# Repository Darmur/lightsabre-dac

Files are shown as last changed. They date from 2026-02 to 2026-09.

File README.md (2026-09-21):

# LightSABRE DAC

**An audiophile Raspberry Pi HAT, given away complete.**

Designed by [Dario “Darmur” Murgia](https://github.com/Darmur). Released under [CC0 1.0](LICENSE).






<p align="center">
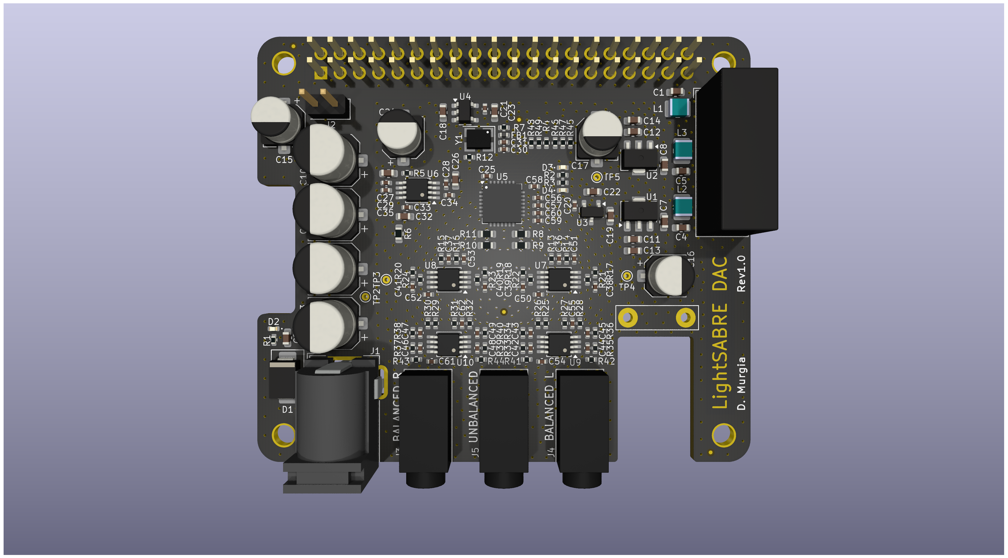
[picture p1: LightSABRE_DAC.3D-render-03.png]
LightSABRE DAC, top view — Rev 1.0 by D. Murgia
  
</p>

LightSABRE is a finished, manufacturable, dual-edition DAC for Raspberry Pi. The Gerbers, pick-and-place, 3D model, and two BOMs — already filled with LCSC, Mouser, and Digi-Key numbers — live in this repository. The work of designing it is done. What remains is to make a board, listen, and share what you heard.

---

## Why this board exists

Open audio hardware is only useful if someone can hold it. LightSABRE is a Raspberry Pi HAT built around a proper Sabre converter, with the analogue, the clocks, and the power that the datasheet assumes and most boards omit.

The name is not decoration. At the centre sits the ESS ES9018K2M, the 32-bit SABRE32 converter that made “Sabre sound” a living-room phrase: HyperStream architecture, on-chip ASRC, and a Time Domain Jitter Eliminator that forgives a Raspberry Pi’s imperfect I²S in a way cheap DAC HATs never do.

The silk reads `D. Murgia  Rev1.0`. The licence is CC0.

> Creative Commons CC0 is not a licence with strings. It is a dedication to the commons. You may manufacture LightSABRE, sell LightSABRE, modify LightSABRE, and say so. The only honest thing to keep is the name on the board.

---

## What you are looking at

<p align="center">
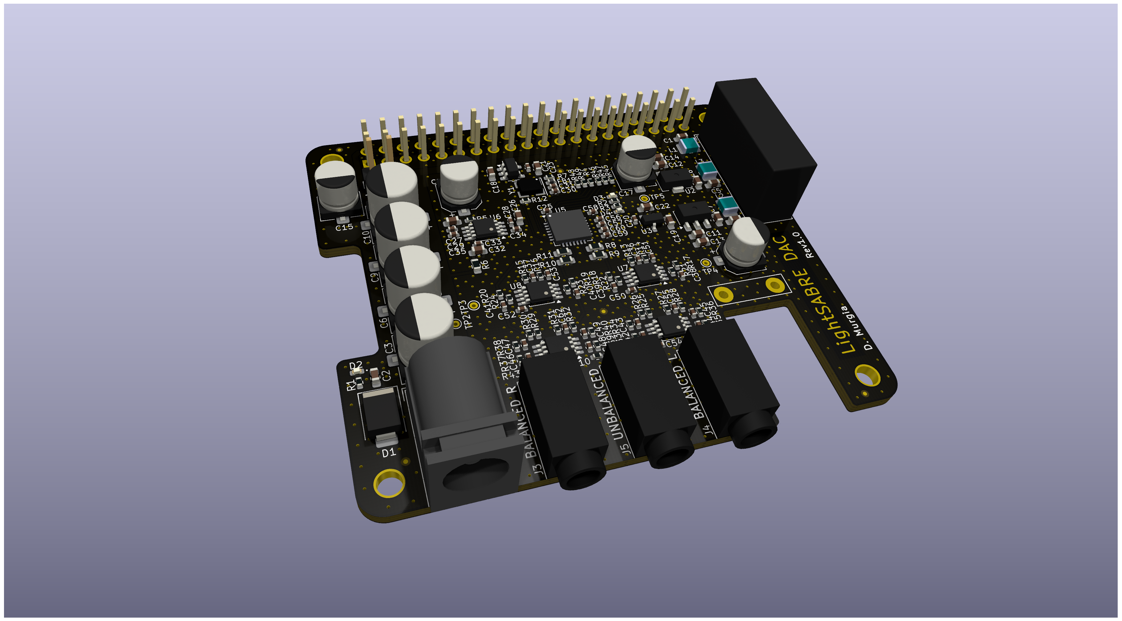
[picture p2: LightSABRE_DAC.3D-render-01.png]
LightSABRE DAC, three-quarter view with barrel jack and three 3.5 mm outputs
  
</p>

LightSABRE is a 65 × 56 mm Raspberry Pi HAT. It sits on the 40-pin GPIO, takes I²S from the Pi, and puts analogue music out of three 3.5 mm jacks:

| Jack (silkscreen) | Part | Wiring on the silk |
| --- | --- | --- |
| **Balanced L** | 3.5 mm PJ-320A | Tip = hot (+), ring = cold (−), sleeve = shield |
| **Balanced R** | 3.5 mm PJ-320A | Tip = hot (+), ring = cold (−), sleeve = shield |
| **Unbalanced** | 3.5 mm PJ-320A | Tip = left, ring = right, sleeve = shield |

The same wiring is engraved on the underside, so a late-night cable session does not require the PDF.

<p align="center">
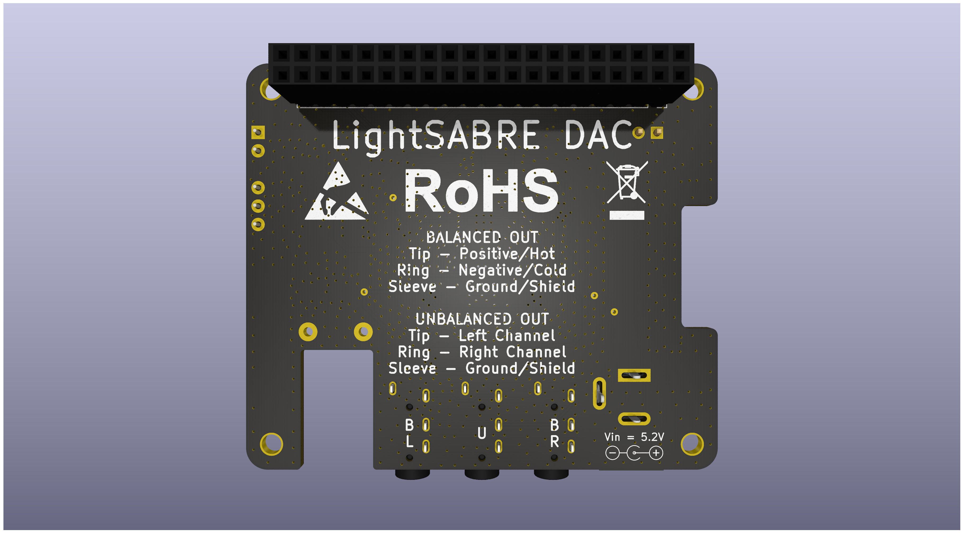
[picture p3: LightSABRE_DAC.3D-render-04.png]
LightSABRE DAC underside — output pinout and 5.2 V input polarity
  
</p>

A 5.5 × 2.0 mm barrel jack feeds the board. The silk says what the analogue section wants to see: **Vin = 5.2 V**, centre positive. A 5.6 V / 5 W SMB zener sits on that input as a clamp, not as a design suggestion to over-volt it.

A two-pin jumper (`J2` / `JP1`) ties the HAT 5 V rail to the Raspberry Pi. Fit it and the HAT can back-power the Pi, or the Pi can feed the HAT. Leave it off if you want the two 5 V domains independent.

---

## The engineering, in the order it matters

Audiophile boards fail in the power supply more often than they fail in the DAC. LightSABRE is laid out around that fact.

### Isolated analogue rails

The 5 V incoming rail does not become the op-amp supply. An isolated 2 W DC/DC module (`A0512S-2WR2`, PS1) creates a galvanically split ±12 V island. Linear 78L09 / 79L09 regulators then drop that island to quiet ±9 V for the analogue stages. The Raspberry Pi’s digital noise stays on its own side of the isolation barrier.

### Split 3.3 V for the Sabre chip

The ES9018K2M is not given a single 3.3 V and a hope.

| Rail | Regulator | Role |
| --- | --- | --- |
| DAC digital 3.3 V | LR6206B-U33 | Digital core and I/O |
| DAC analogue 3.3 V | Texas Instruments **TPS7A20** (TPS7A2033) | Low-noise analogue / clock domain |

That split — a workhorse regulator for digital, a Texas Instruments ultra-low-noise LDO for analogue — is the difference between a Sabre chip that can still measure like the datasheet and a Sabre chip that measures like a phone dongle.

### The conversion, treated as analogue

The DAC current comes out of the ES9018K2M and meets a discrete I/V and line stage built from five dual audio op-amps (`U6`–`U10`). The gain-setting resistors are 806 Ω, 0.1 %, thin-film 0402 parts — twenty of them — because current-to-voltage is where a Sabre board either becomes transparent or becomes a tone control. The filter capacitors in that path are C0G/NP0 (2.2 nF 2 % and 470 pF), not the X5R that is cheaper to pick.

Five dual packages is not excess. They implement the current-to-voltage conversion and the balanced plus unbalanced line stages, so the single-ended jack is a real analogue output rather than one half of a differential pair left hanging.

### A clock that is not an afterthought

Y1 is a 100 MHz, 3.3 V, 3225 CMOS oscillator, the frequency the ES9018K2M actually wants. The Standard and Pro editions differ here on purpose — see below — but both editions give the converter its own oscillator rather than begging a clock from the Pi.

### A HAT that behaves like a HAT

The board is a mechanical HAT: 65.1 × 56.1 mm, 1.6 mm FR4, 40-pin extended socket, mounting holes, and a cut-out that clears the Pi’s connectors. I²S, I²C, and the usual GPIO pass through. The converter’s I²C address is `0x90` in 8-bit notation, which is **`0x48`** in the 7-bit notation every Linux driver uses.

<p align="center">
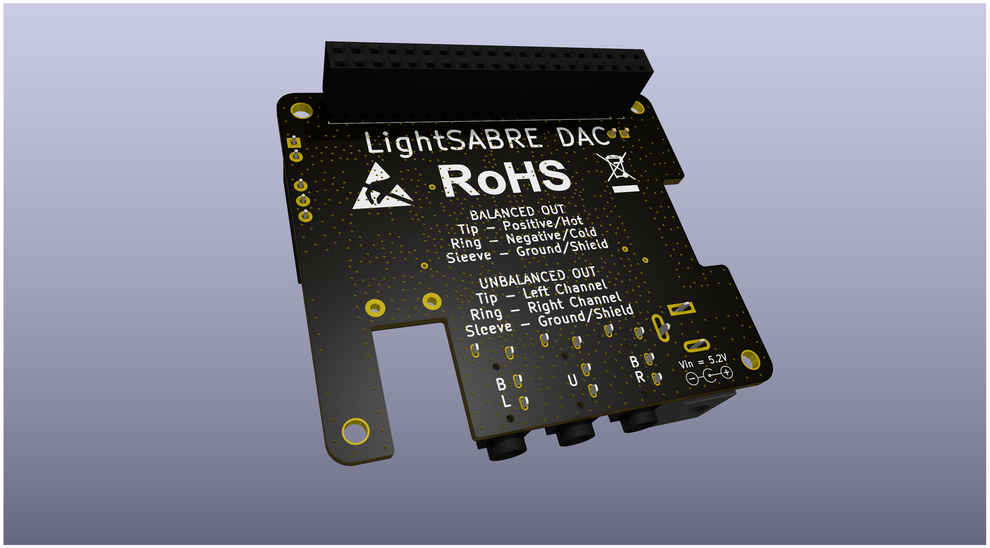
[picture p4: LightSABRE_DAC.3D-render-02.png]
LightSABRE DAC, underside three-quarter view
  
</p>

---

## Standard and Pro

One PCB. Two bills of materials. The difference is not a marketing sticker — it is two parts, chosen because they sit in the two places a listener can still hear after the power architecture is already right.

| | **Standard** — `LightSABRE_DAC.bom.varA.xlsx` | **Pro** — `LightSABRE_DAC.bom.varB.xlsx` |
| --- | --- | --- |
| **Op-amps U6–U10** | Texas Instruments **OPA1678** | Texas Instruments **OPA1602** |
| **Op-amp character** | SoundPlus FET-input, 4.5 nV/√Hz, the honest high-performance default | SoundPlus bipolar-input, 1.1 nV/√Hz, the quieter, more expensive sibling |
| **Oscillator Y1** | CMOS crystal oscillator, 100 MHz / 20 ppm (`O93225100MEDA4SI-13`) | SiTime **SiT8209** MEMS oscillator, 100 MHz / 20 ppm |
| **Clock character** | Correct frequency, serviceable jitter, easy to source | MEMS stability, vibration immunity, the part you specify when the rest of the board deserves it |
| **Everything else** | Identical | Identical |

The isolated DC/DC, the TPS7A20, the 0.1 % I/V resistors, the C0G filter caps, the Sabre chip, the jacks, and the HAT mechanics do not change. This is not a “lite” board and a “real” board. It is one analogue design and two component grades, so a first build can be affordable and a second build can be uncompromising without a respin.

If you are assembling a single board and the Pro parts are in stock, fit the Pro parts. If you are assembling a small run and want every unit to exist, Standard is not a consolation prize.

---

## What the converter will do

From the ES9018K2M, once the board around it is this careful:

- PCM up to **32-bit / 384 kHz**
- DSD up to **DSD256**
- On-chip ASRC and jitter elimination
- Datasheet territory of **127 dB DNR** and **−120 dB THD+N**
- I²C register map for volume, filters, and de-emphasis

Those figures are the chip’s. The board is designed so they remain plausible after the signal has left the QFN.

---

## Repository contents

Everything required to order, assemble, inspect, and understand Rev 1.0.

| File | What it is |
| --- | --- |
| `LightSABRE_DAC.kicad_pro` / `.kicad_sch` / `.kicad_pcb` | KiCad 9 project. Sheets: **power**, **audio**, **interface**. |
| `power.kicad_sch` | Input protection, isolated ±12 V, ±9 V analogue, split 3.3 V. |
| `audio.kicad_sch` | ES9018K2M, clock, I/V, balanced and unbalanced outputs. |
| `interface.kicad_sch` | Raspberry Pi 40-pin HAT pinout, I²S and I²C. |
| `LightSABRE_DAC.sch.pdf` | Printable schematic. |
| `LightSABRE_DAC.pcb.pdf` | Printable board. |
| `LightSABRE_DAC.bom.varA.xlsx` | **Standard** BOM with MPN, LCSC, Mouser, Digi-Key. |
| `LightSABRE_DAC.bom.varB.xlsx` | **Pro** BOM. Same columns. Different U6–U10 and Y1. |
| `LightSABRE_DAC.pos.csv` | Centroid / pick-and-place. |
| `LightSABRE_DAC.gerber_x1.2-Layers.zip` | 2-layer Gerbers, classic Protel extensions. |
| `LightSABRE_DAC.gerber_x1.4-Layers.zip` | 4-layer Gerbers, classic Protel extensions. |
| `LightSABRE_DAC.gerber_x2.2-Layers.zip` | 2-layer Gerbers, KiCad X2 / `.gbr` naming, split PTH/NPTH drills. |
| `LightSABRE_DAC.gerber_x2.4-Layers.zip` | 4-layer Gerbers, KiCad X2 naming. |
| `LightSABRE_DAC.3D-model.step` | Full 3D for enclosure work. |
| `LightSABRE_DAC.3D-render-0[1-4].png` | The renders on this page. |
| `LICENSE` | CC0 1.0 Universal. |

---

## Make one

The manufacturing pack is not a teaser. It is the order.

### 1. Choose a stack-up

Both 2-layer and 4-layer plots are in the tree. The design rules are 0.1524 mm (6 mil) clearance and trace, 35 µm copper, 1.6 mm finished thickness.

**Order the 4-layer board** unless a fab house forces the issue. Inner planes are how a Sabre HAT keeps digital return current out of the analogue. The 2-layer set exists so the project remains buildable when a four-layer panel is not.

Suggested 4-layer reading of the exported job file:

| Layer | Role |
| --- | --- |
| F.Cu | Signals, analogue, components |
| In1.Cu | Plane |
| In2.Cu | Plane |
| B.Cu | Signals and HAT socket |

Finish is left open in the job file. ENIG is the grown-up choice for a 0.5 mm-pitch QFN and 0402 I/V network; HASL will work if the assembler is honest about it.

### 2. Choose a Gerber dialect

| Archive prefix | Give this to |
| --- | --- |
| `gerber_x1.*` | Fabs that still want `.gtl` / `.gbl` / `.gto` and a single `.drl` |
| `gerber_x2.*` | Fabs that want modern `.gbr` names and separate PTH / NPTH drills |

If you are unsure, send `LightSABRE_DAC.gerber_x2.4-Layers.zip` and the matching BOM. Most houses in 2026 prefer it.

### 3. Choose Standard or Pro

Upload `LightSABRE_DAC.bom.varA.xlsx` or `LightSABRE_DAC.bom.varB.xlsx` with `LightSABRE_DAC.pos.csv`. LCSC numbers are already in the sheets. Fiducials `FID1`–`FID6` are on the board because this was always meant to go through a pick-and-place.

### 4. Respect the parts that look small

This is not a first hot-air project.

- ES9018K2M is a **5 × 5 mm QFN-28**, 0.5 mm pitch, thermal pad with vias
- Most of the analogue network is **0402**
- The I/V resistors are 0.1 % thin film — do not “equivalent” them to 1 % thick film
- The barrel jack is **5.5 × 2.0 mm**, not the more common 2.1 mm pin
- The isolated DC/DC is a tall SIP. Check enclosure height before you print a case

Professional assembly is the path that honours the layout. A careful hand build is possible; a careless one will spend three evenings chasing a pin that the stencil would have got in eight seconds.

### 5. First power, before first music

1. Inspect the QFN and the DC/DC orientation.
2. Leave `JP1` off.
3. Feed **5.2 V** centre-positive into `J1`. Confirm the input LED.
4. Measure the isolated island: roughly ±12 V after PS1, ±9 V after U1/U2.
5. Measure both 3.3 V rails at the DAC.
6. Only then seat the HAT on a Pi, decide whether `JP1` should be on, and bring I²S up.

If a rail is wrong, stop. The gift is a working board, not a smoked Sabre.

---

## Bring it up on a Raspberry Pi

LightSABRE speaks the language every Pi DAC already speaks.

- **I²S** from the 40-pin header into the ES9018K2M
- **I²C** at **0x48** (7-bit) for volume, filters, and mute
- Overlay starting point on Raspberry Pi OS / Volumio / moOde / DietPi: a generic I²S DAC, then an ES9018K2M userspace or kernel client if you want hardware volume

Use what fits. Publish what you change.

Suggested first listen, so reports can be compared:

- Same file, same headphones or the same pair of TRS cables
- Unbalanced jack first, then balanced into something that can take it
- One track you know too well, one you have never heard on a Sabre chip
- Note the edition (Standard or Pro), the stack-up (2-layer or 4-layer), the Pi model, and the player

---

## The invitation

The expensive part is already in the tree: the thinking, the layout, the variants, the fab files, and the decision to give them away.

The interesting part left is not another respin. It is a board that exists, a listening chair, and a short write-up that the next builder can trust.

Build a Standard. Build a Pro. Build one of each and swap only the op-amps in your notes. Photograph the underside. Post the first-power rail measurements. Say whether the isolated island was worth it on *your* Pi. Open an issue, or a pull request with a build log, or a thread wherever you already talk about DACs.

If the board taught you something, write it down. That is how an open hardware gift stays alive after the ZIP files stop being news.

---

## Author

**Dario Murgia ([Darmur](https://github.com/Darmur))**  
Italian electronics engineer. Other open audio boards: [BassOwl-HAT](https://github.com/Darmur/bassowl-hat), [BassOwl-Lite](https://github.com/Darmur/bassowl-lite), [BassFly-uHAT](https://github.com/Darmur/bassfly-uhat), [BassCrab-uHAT](https://github.com/Darmur/basscrab-uhat), [tubeamp](https://github.com/Darmur/tubeamp). Schematic title block: *itz-embedded*, 2026-01-09, Rev 1.0.

---

## License

[CC0 1.0 Universal](LICENSE). To the extent possible under law, the author has waived all copyright and related rights to this work.

ESS SABRE, SABRE32, and related marks are trademarks of ESS Technology, Inc. Raspberry Pi is a trademark of Raspberry Pi Ltd. Texas Instruments and SiTime part names are used here as the actual parts on the BOMs.

---

<p align="center"><em>Make the board. Listen for a week. Tell someone what it did.</em></p>

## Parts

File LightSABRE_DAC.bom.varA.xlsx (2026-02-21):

Qty | Reference | Descr | MPN | Footprint | Datasheet | Value | MOUSER | DIGIKEY | LCSC
14 | C1, C4, C5, C7, C8, C13, C14, C18, C19, C22, C23, C26, C27, C32 | CAP CER 10UF 20% 16V X5R 0603 | HGC0603R5106M160NTHJ | Capacitor_SMD:C_0603_1608Metric | ~ | CAP-10U-20%-16V-X5R-0603_004 | - | - | C7472959
3 | C2, C11, C12 | CAP CER 100NF 10% 50V X7R 0603 | CGA0603X7R104K500JT | Capacitor_SMD:C_0603_1608Metric | ~ | CAP-100N-10%-50V-X7R-0603_002 | - | - | C6119867
4 | C3, C6, C9, C10 | CAP ALUM 470UF 20% 10V SMD | RVT1A471M0607 | Capacitor_SMD:CP_Elec_6.3x7.7 | https://www.lcsc.com/datasheet/lcsc_datasheet_2411220152_ROQANG-RVT1A471M0607_C335982.pdf | CAP-EL-470U-20%-10V-ALUM-6.3MM-7.7MM_002 | - | - | C335982
4 | C15, C16, C17, C24 | CAP ALUM 100UF 20% 16V SMD | RVT1C101M0505 | Capacitor_SMD:CP_Elec_5x5.4 | https://www.lcsc.com/datasheet/lcsc_datasheet_2411121455_ROQANG-RVT1C101M0505_C2977550.pdf | CAP-EL-100U-20%-16V-ALUM-5.0MM-5.4MM_002 | - | - | C2977550
6 | C20, C21, C28, C29, C31, C33 | CAP CER 100NF 10% 16V X7R 0402 | FCC0402B104K160AT | Capacitor_SMD:C_0402_1005Metric | ~ | CAP-100N-10%-16V-X7R-0402_002 | - | - | C5137468
12 | C25, C30, C34, C35, C50, C51, C52, C53, C54, C55, C61, C62 | CAP CER 2.2UF 20% 16V X5R 0402 | CGA0402X5R225M160GT | Capacitor_SMD:C_0402_1005Metric | ~ | CAP-2.2U-20%-16V-X5R-0402_002 | - | - | C6119773
7 | C36, C37, C56, C57, C58, C59, C60 | CAP CER 4.7UF 20% 10V X5R 0402 | HGC0402R5475M100NTEJ | Capacitor_SMD:C_0402_1005Metric | ~ | CAP-4.7U-20%-10V-X5R-0402_002 | - | - | C7472957
4 | C38, C39, C40, C41 | CAP CER 470PF 5% 50V C0G 0402 | CGA0402C0G471J500GT | Capacitor_SMD:C_0402_1005Metric | ~ | CAP-470P-5%-50V-C0G-0402_002 | - | - | C20069335
8 | C42, C43, C44, C45, C46, C47, C48, C49 | CAP CER 2.2NF 2% 50V C0G 0402 | GRM1555C1H222GA01D | Capacitor_SMD:C_0402_1005Metric | ~ | CAP-2.2N-2%-50V-C0G-0402_001 | 81-GRM1555C1H222GA1D | 490-GRM1555C1H222GA01DCT-ND | C2987940
1 | D1 | DIODE ZENER 5.6V 5W SMB | SMBJ5339B | Diode_SMD:D_SMB | https://datasheet.lcsc.com/lcsc/2207271730_LGE-SMBJ5339B_C5122124.pdf | ZENER-5.6V-5W-SMB_003 | - | - | C5122124
3 | D2, D3, D4 | LED RED CLEAR 0402 | XL-1005SURC | LED_SMD:LED_0402_1005Metric | https://www.lcsc.com/datasheet/C25503345.pdf | LED-RED-0402_002 | - | - | C25503345
1 | FB1 | FERRITE BEAD 600OHM@100MHZ 0.7A 0.34OHM 0402 | PBY100505T-601Y-N | Inductor_SMD:L_0402_1005Metric | https://datasheet.lcsc.com/lcsc/1811141621_Chilisin-Elec-PBY100505T-601Y-N_C142082.pdf | FERR-BEAD-600OHM@100MHZ-0.7A-0.34OHM-0402 | - | - | C142082
1 | J1 | DC BARREL JACK 5.5X2.0MM TH | DC-005 5.5-2.0MM | dm_CONN:BarrelJack | https://datasheet.lcsc.com/lcsc/1811051112_BOOMELE-Boom-Precision-Elec-DC-005-2-0_C16214.pdf | BARREL-JACK-SW_002 | - | - | C16214
1 | J2 | CONN HEADER TH 2POS 01X02 2.54MM | C124375 | Connector_PinHeader_2.54mm:PinHeader_2x01_P2.54mm_Vertical | https://datasheet.lcsc.com/szlcsc/1811151421_Ckmtw-Shenzhen-Cankemeng-C124375_C124375.pdf | CONN-HDR-01X02-2.54-TH_002 | - | - | C124375
3 | J3, J4, J5 | AUDIO JACK 3.5" 4 POLES TRRS TH | PJ-320A | dm_CONN:TRRS-PJ-320A | https://datasheet.lcsc.com/szlcsc/1912111437_SHOU-HAN-PJ-320D_C431535.pdf | PJ-320A | - | - | C2884926
1 | J6 | CONN SOCKET TH 40POS 02X20 2.54MM EXT PIN | 2.54-2*20PPC104 | dm_CONN:SKT-02x20-TH-EXT | https://www.lcsc.com/datasheet/lcsc_datasheet_1811132110_BOOMELE-Boom-Precision-Elec-2-54-2-20PPC104_C35165.pdf | RPi-GPIO-SKT-TH-EXT_002 | - | - | C35165
1 | JP1 | CONN SHUNT 2POS 2.54MM BLACK CAPPED | HY-2540-B1NIB |  | https://www.lcsc.com/datasheet/lcsc_datasheet_2410122012_HanElectricity-HY-2540-B1NIB_C18185738.pdf | CONN-SHUNT-2P-2.54MM-BLACK-CAPPED_002 | - | - | C18185738
3 | L1, L2, L3 | IND 4.7 UH 20% 1.55A 0.196 OHM 1008 | WIP252012P-4R7ML | dm_SMD:L_1008_2520Metric | https://www.lcsc.com/datasheet/lcsc_datasheet_2410121513_INPAQ-WIP252012P-4R7ML_C964123.pdf | IND-4.7U-20%-1.55A-0.196OHM-1008_002 | - | - | C964123
1 | PS1 | ISOLATED DC DC CONVERTER 5V DUAL OUT+/-12V 2W SIP | A0512S-2WR2 | Converter_DCDC:Converter_DCDC_XP_POWER-IHxxxxS_THT | https://www.lcsc.com/datasheet/lcsc_datasheet_2401211050_YLPTEC-A0512S-2WR2_C5369424.pdf | A0512S-2W-1.5KV-SIP_002 | - | - | C5369424
3 | R1, R2, R3 | RES 1K OHM 5% 1/16W 0402 | 0402WGJ0102TCE | Resistor_SMD:R_0402_1005Metric | ~ | RES-1K-5%-0.063W-0402_002 | - | - | C25543
5 | R4, R5, R7, R13, R15 | RES 10K OHM 1% 1/16W 0402 | RTT021002FTH | Resistor_SMD:R_0402_1005Metric | ~ | RES-10K-1%-0.063W-0402_002 | - | - | C102749
1 | R6 | RES 3.3 OHM 1% 1/10W 0603 | FRC0603F3R30TS | Resistor_SMD:R_0603_1608Metric | ~ | RES-3.3-1%-0.1W-0603_002 | - | - | C2930016
4 | R8, R9, R10, R11 | RES 0 OHM 1% 1/16W 0603 | FRC0603F0000TS | Resistor_SMD:R_0603_1608Metric | ~ | RES-0-1%-0.1W-0603_002 | - | - | C2906974
14 | R12, R17, R18, R19, R20, R41, R42, R43, R44, R45, R46, R47, R48, R49 | RES 10 OHM 1% 1/16W 0402 | FRC0402F10R0TS | Resistor_SMD:R_0402_1005Metric | ~ | RES-10-1%-0.063W-0402_002 | - | - | C2906862
2 | R14, R16 | RES 3.9K OHM 1% 1/16W 0402 | FRC0402F3901TS | Resistor_SMD:R_0402_1005Metric | ~ | RES-3.9K-1%-0.063W-0402_002 | - | - | C2909346
20 | R21, R22, R23, R24, R25, R26, R27, R28, R29, R30, R31, R32, R33, R34, R35, R36, R37, R38, R39, R40 | RES 806 OHM 0.1% 1/16W THIN FILM 0402 | RT0402BRD07806RL | Resistor_SMD:R_0402_1005Metric | ~ | RES-806-0.1%-0.063W-THIN-0402_001 | 603-RT0402BRD07806RL | YAG1481CT-ND | C852922
1 | U1 | IC REG LINEAR 9V 100MA SOT89-3 | 78L09 | dm_SMD:SOT-89-3 | https://www.lcsc.com/datasheet/lcsc_datasheet_2410121529_HL-78L09_C22458782.pdf | 78L09-SOT89_002 | - | - | C22458782
1 | U2 | IC REG LINEAR -9V 100MA SOT89-3 | PJ79L09SQ | dm_SMD:SOT-89-3 | https://www.lcsc.com/datasheet/lcsc_datasheet_2410221617_PJSEMI-PJ79L09SQ_C41784049.pdf | 79L09-SOT89_002 | - | - | C41784049
1 | U3 | IC REG LINEAR 3.3V 300MA SOT23-3 | LR6206B-U33 | Package_TO_SOT_SMD:SOT-23 | https://www.lcsc.com/datasheet/lcsc_datasheet_2212192008_LR-LR6206B-U33_C5336486.pdf | LR6206B-U33 | - | - | C5336486
1 | U4 | IC REG LINEAR 3.3V 300MA LOW-NOISE SOT23-5 | TPS7A2033PDBVR | Package_TO_SOT_SMD:SOT-23-5 | https://www.ti.com/lit/ds/symlink/tps7a20.pdf | TPS7A2033-SOT23 | 595-TPS7A2033PDBVR | 296-TPS7A2033PDBVRCT-ND | C2862740
1 | U5 | IC DAC 16/24/32BIT 384K DSD256 QFN28 | ES9018K2M | dm_SMD:QFN-28-1EP_5x5mm_P0.5mm_EP3.25x3.25mm_ThermalVias_0.3mm | https://www.mouser.com/datasheet/3/3763/1/ES9018K2M-Datasheet-v3.7.pdf | ES9018K2M | 460-ES9018K2M | - | C2688377
5 | U6, U7, U8, U9, U10 | IC OPAMP AUDIO 2 CIRCUIT 4.5V/36V VSSOP-8 | OPA1678IDGKR | Package_SO:MSOP-8_3x3mm_P0.65mm | https://www.ti.com/lit/ds/symlink/opa1678.pdf | OPA1678-VSSOP | 595-OPA1678IDGKR | 296-47667-1-ND | C2863133
1 | Y1 | OSC 3.3V 100MHZ 20PPM 3225 | O93225100MEDA4SI-13 | dm_SMD:Oscillator_SMD_4Pin_3.2x2.5mm | https://www.lcsc.com/datasheet/C496694.pdf | OSC-XO-100M-3225_002 | - | - | C496694

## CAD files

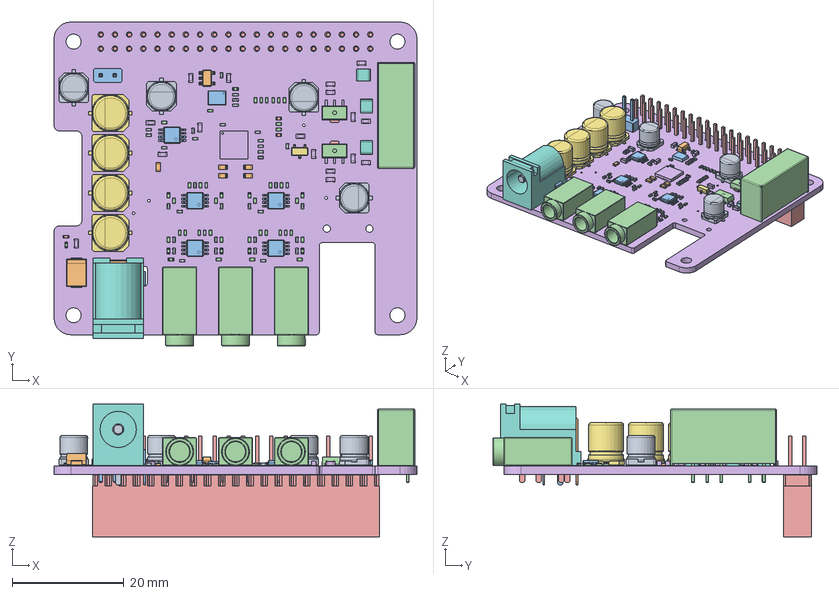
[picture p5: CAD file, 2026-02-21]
LightSABRE_DAC.3D-model.step
65.0 x 58.0 x 23.7 mm
C_0402_1005Metric x 37
D_SMB
OSC_SMD_3225
R_0402_1005Metric x 44
LED_0402_1005Metric x 3
C_0603_1608Metric x 17
CP_Elec_6.3x7.7 x 4
L_1008_2520Metric x 3
CP_Elec_5x5.4 x 4
R_0603_1608Metric x 5
MSOP-8_3x3mm_P0.65mm x 5
PJ-320A x 3
QFN28_5x5_0.5
L_0402_1005Metric
SOT-23-5
PinHeader_2x01_P2.54mm_Vertical
Volumio_Zero-HAT 1.95.1 x 2
SOT-23
BarrelJack
Converter_DCDC_XP_POWER-IHxxxxS_THT
SKT-02x20-TH-EXT
LightSABRE_DAC_PCB

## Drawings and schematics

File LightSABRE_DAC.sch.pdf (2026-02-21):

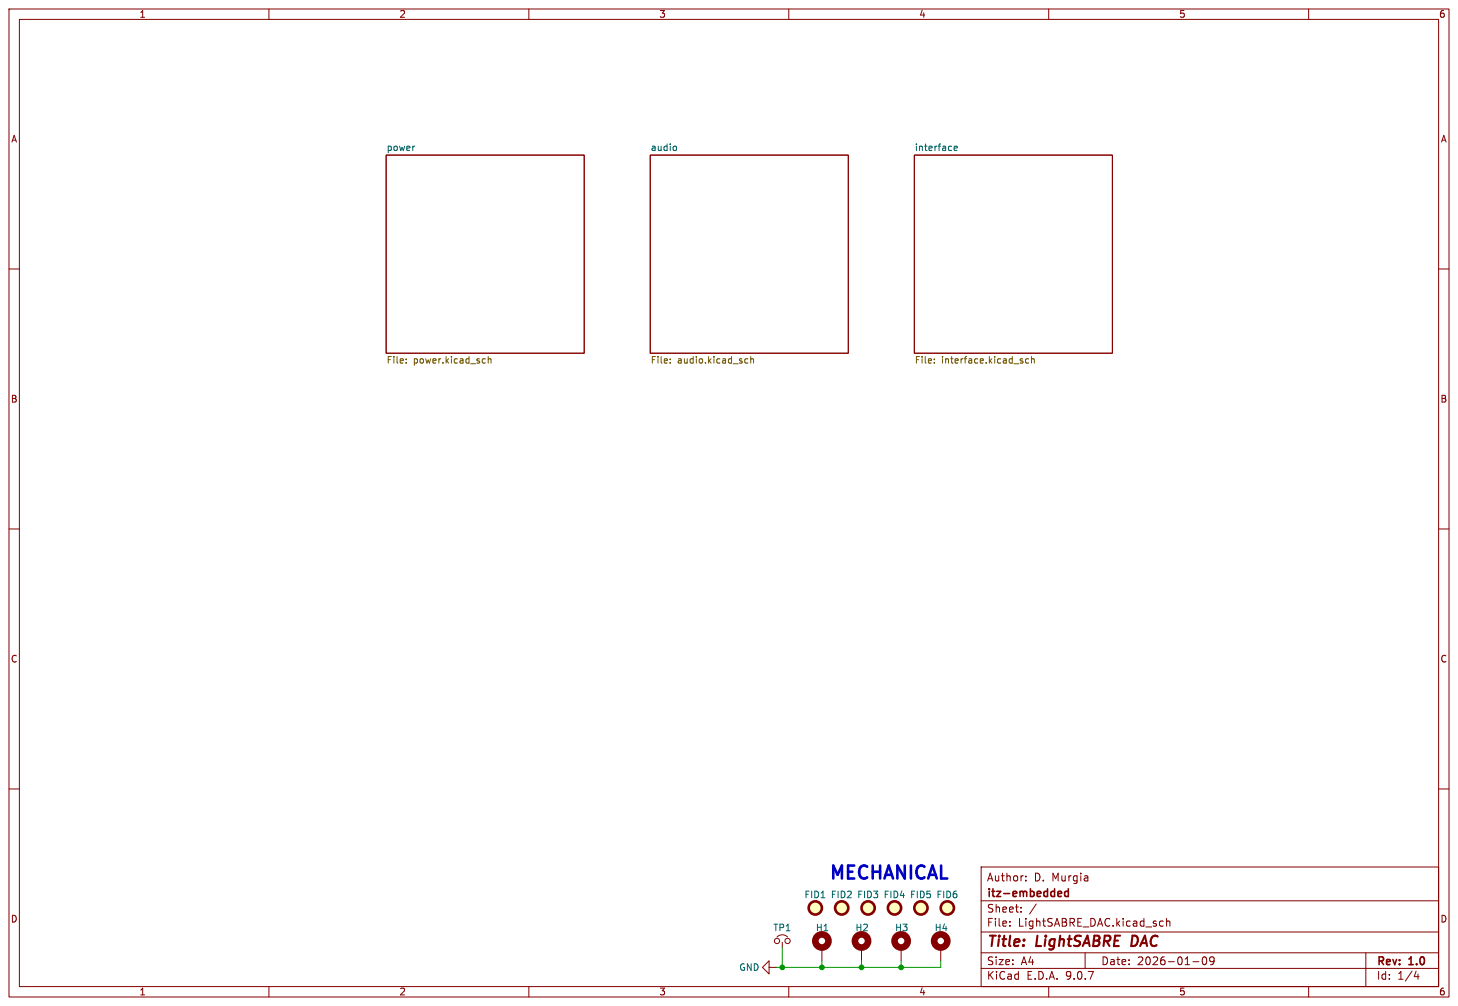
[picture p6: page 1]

Id: 1/4 Title: LightSABRE DAC

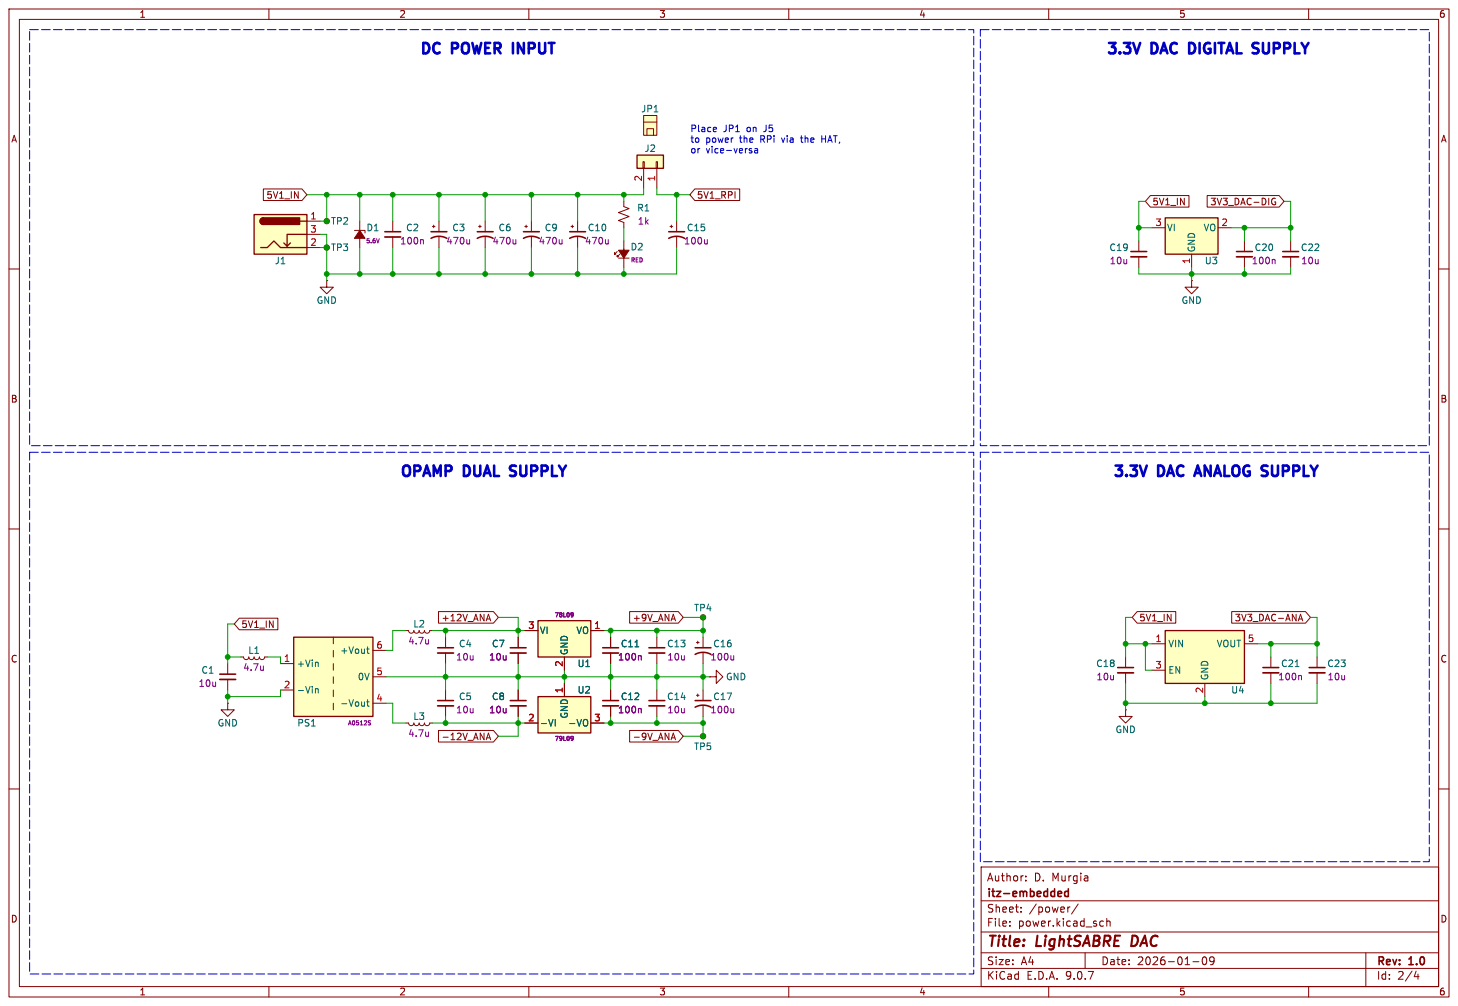
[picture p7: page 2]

Id: 2/4 Title: LightSABRE DAC

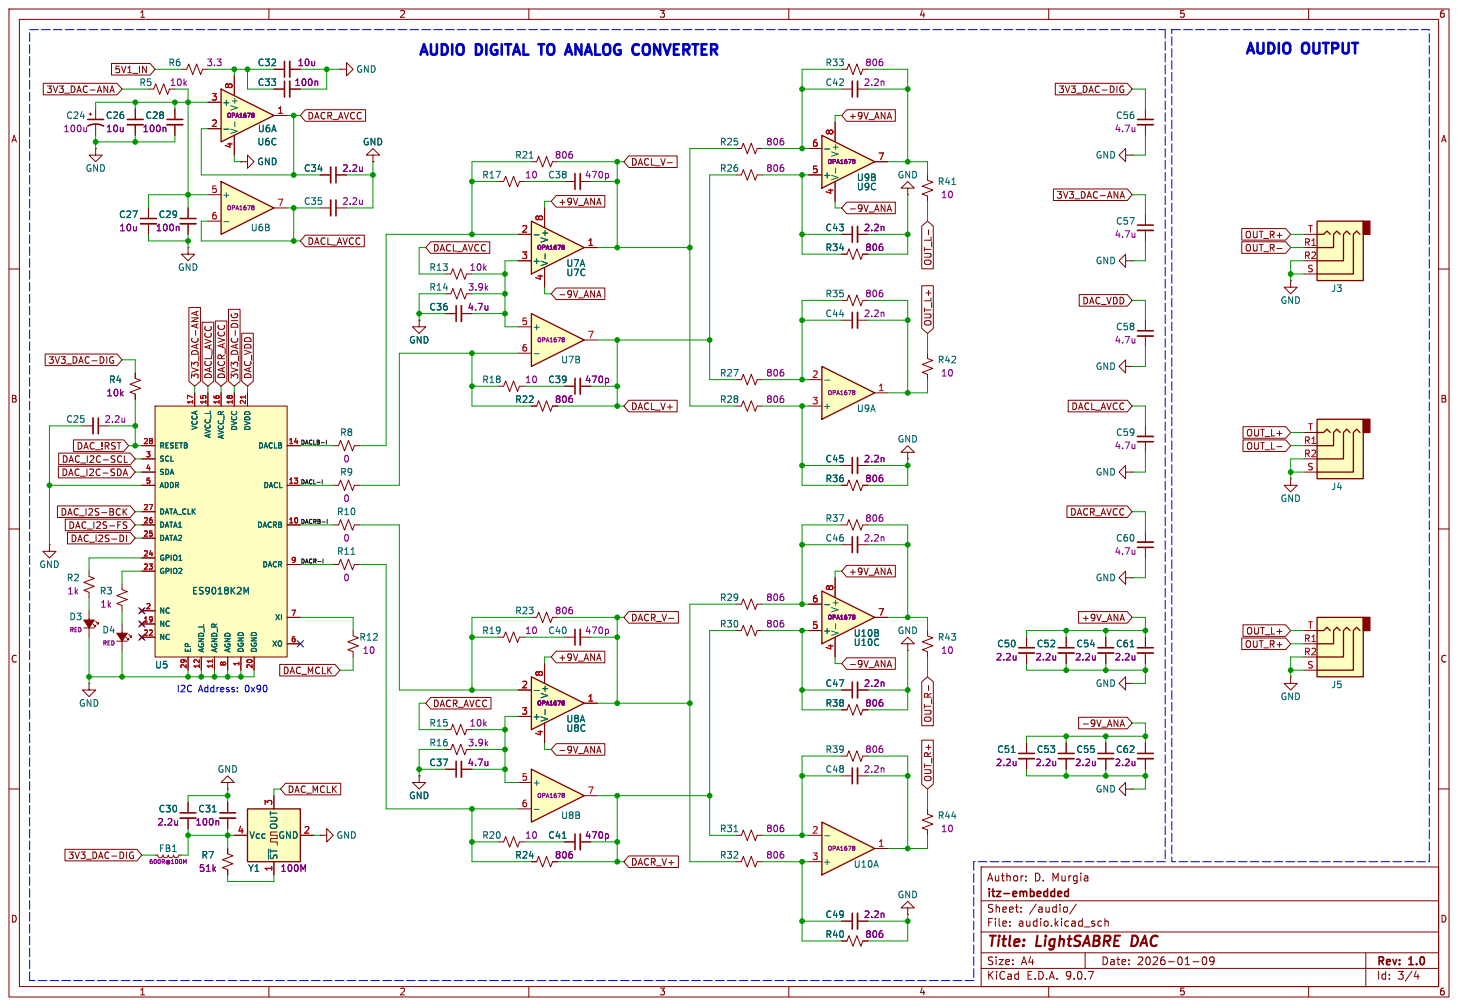
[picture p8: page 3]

1 DVDD 21 DGND 20 DACLB 14 DACL 13 DACRB 10 DACR 9 XI 7 XO 6 U5 ES9018K2M

1 DVDD 21 DGND 20 DACLB 14 DACL 13 DACRB 10 DACR 9 XI 7 XO 6 GND

File: audio.kicad_sch Sheet: /audio/
Id: 3/4 Title: LightSABRE DAC

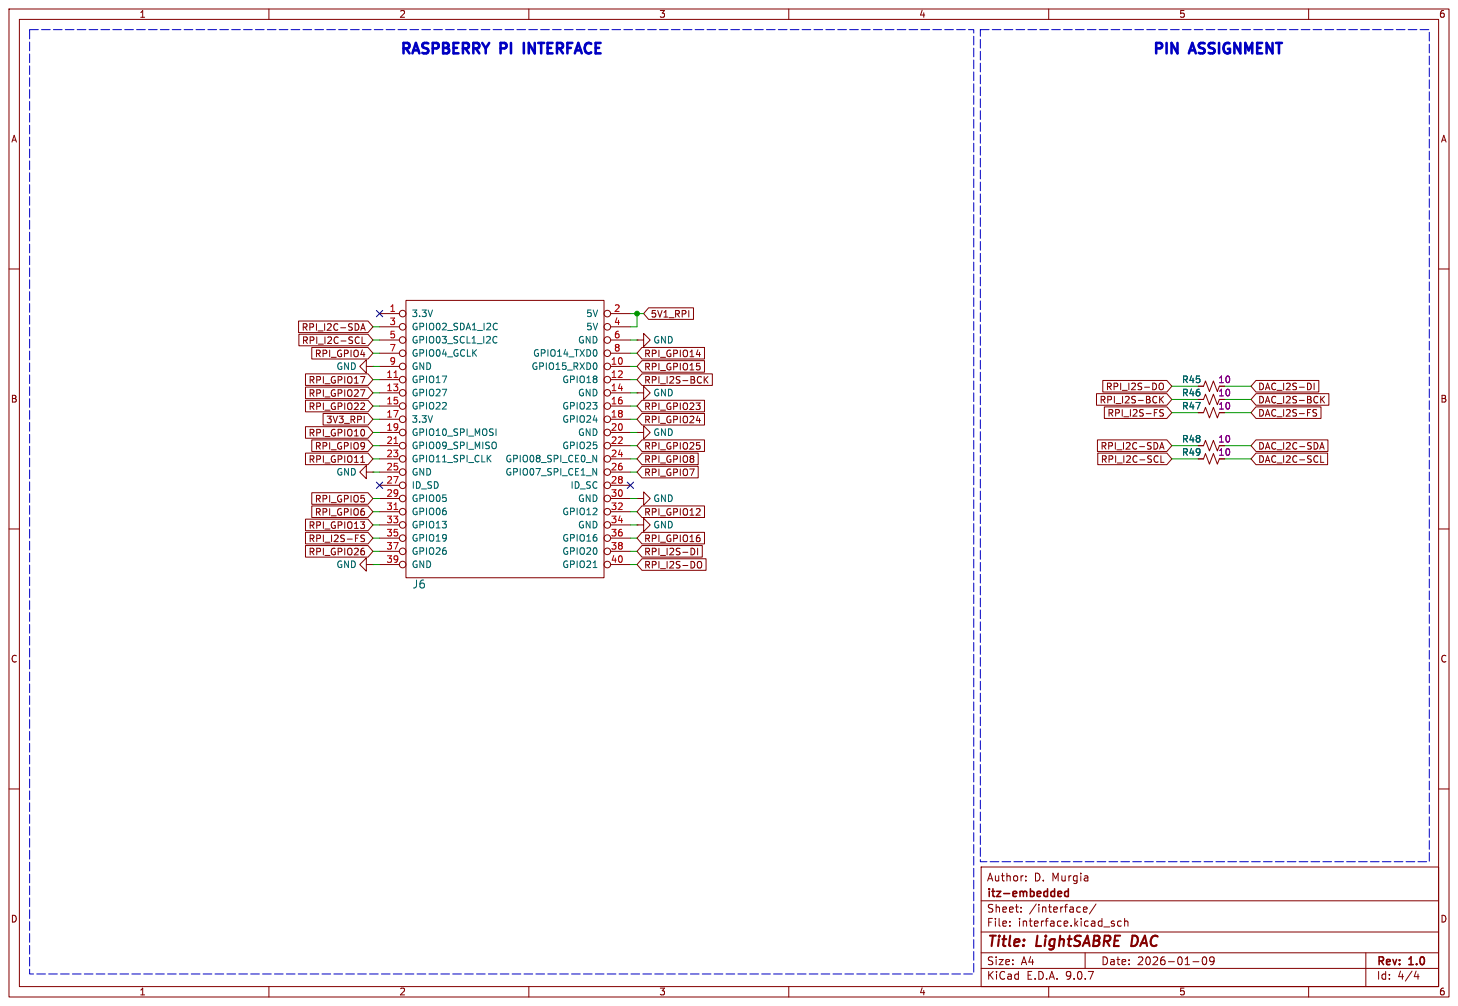
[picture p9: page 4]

File: interface.kicad_sch Sheet: /interface/
Id: 4/4 Title: LightSABRE DAC

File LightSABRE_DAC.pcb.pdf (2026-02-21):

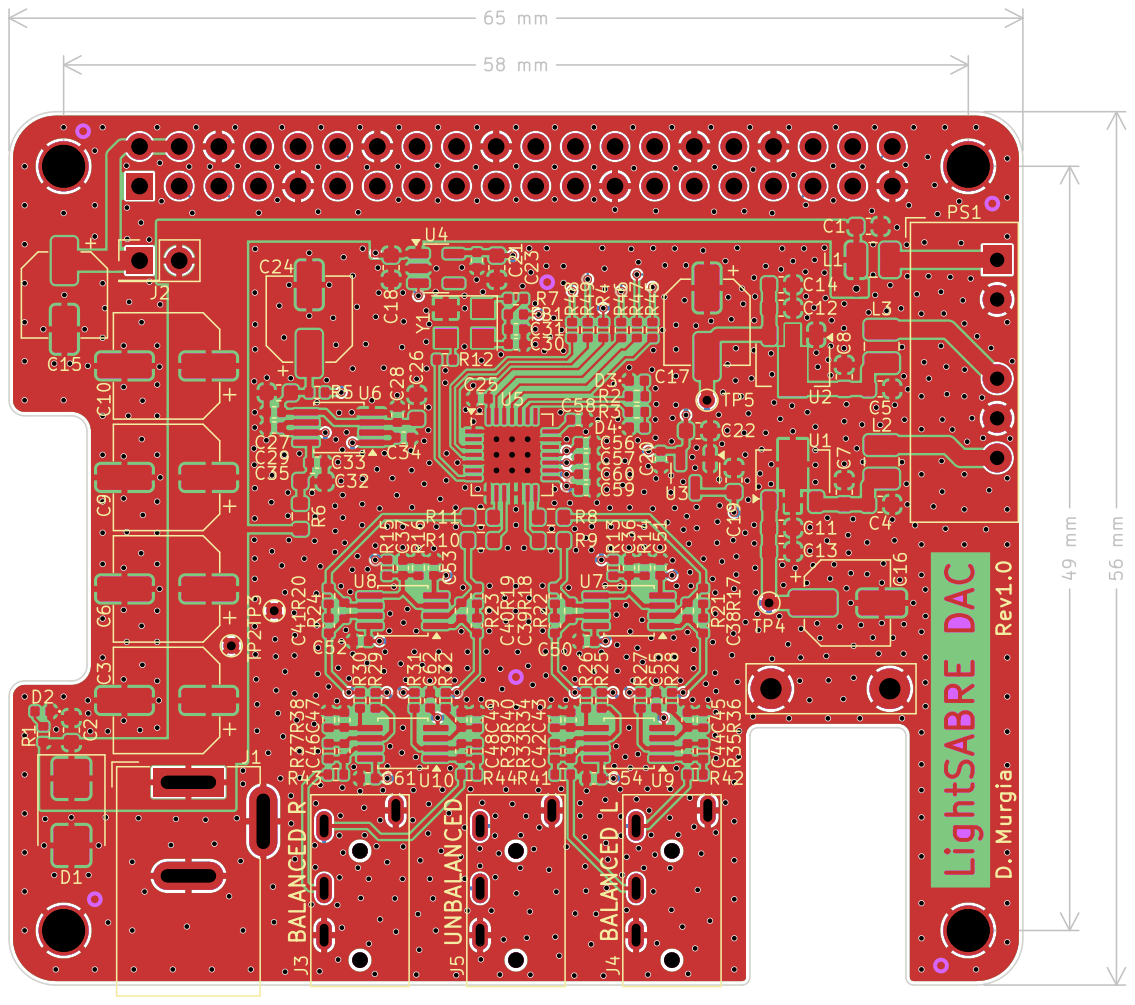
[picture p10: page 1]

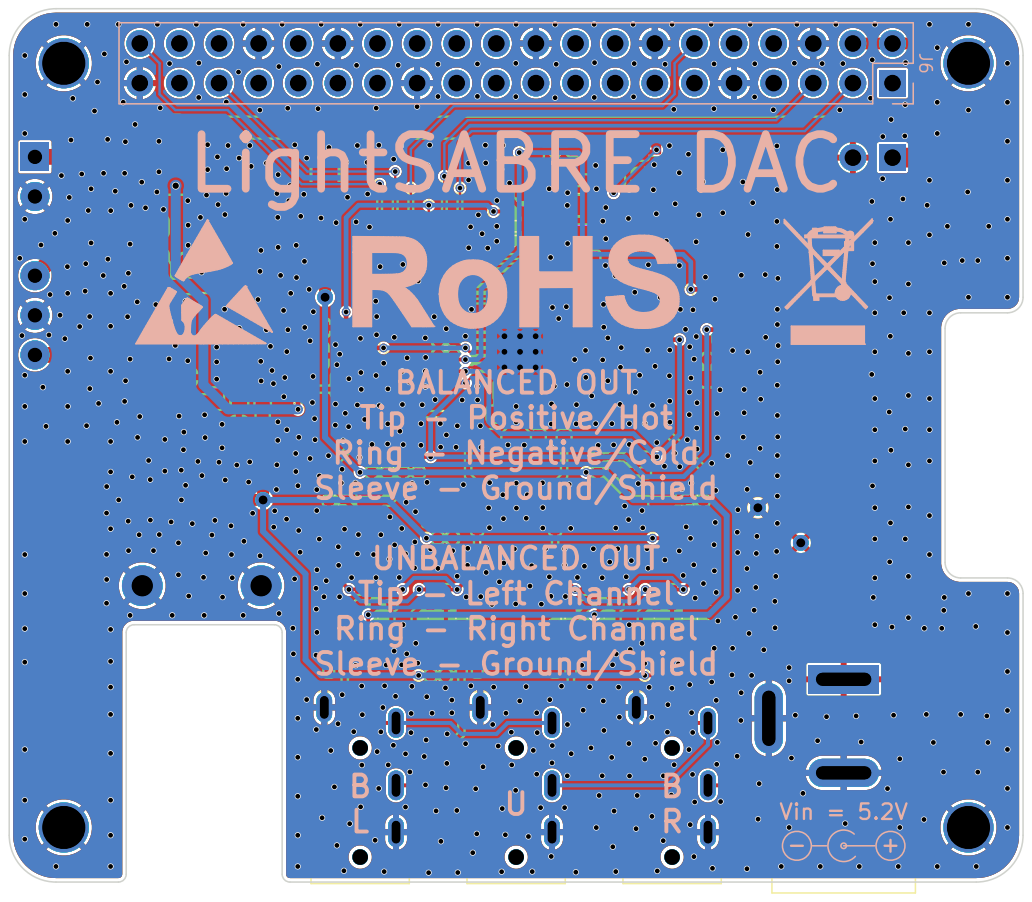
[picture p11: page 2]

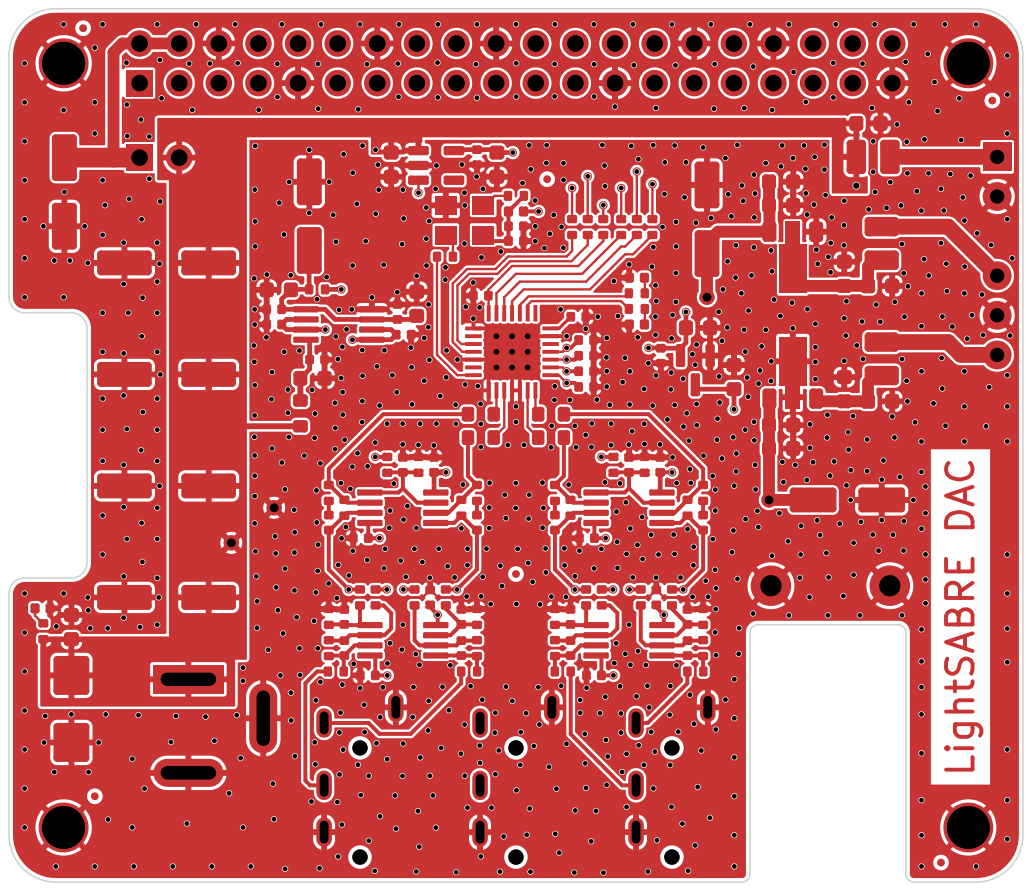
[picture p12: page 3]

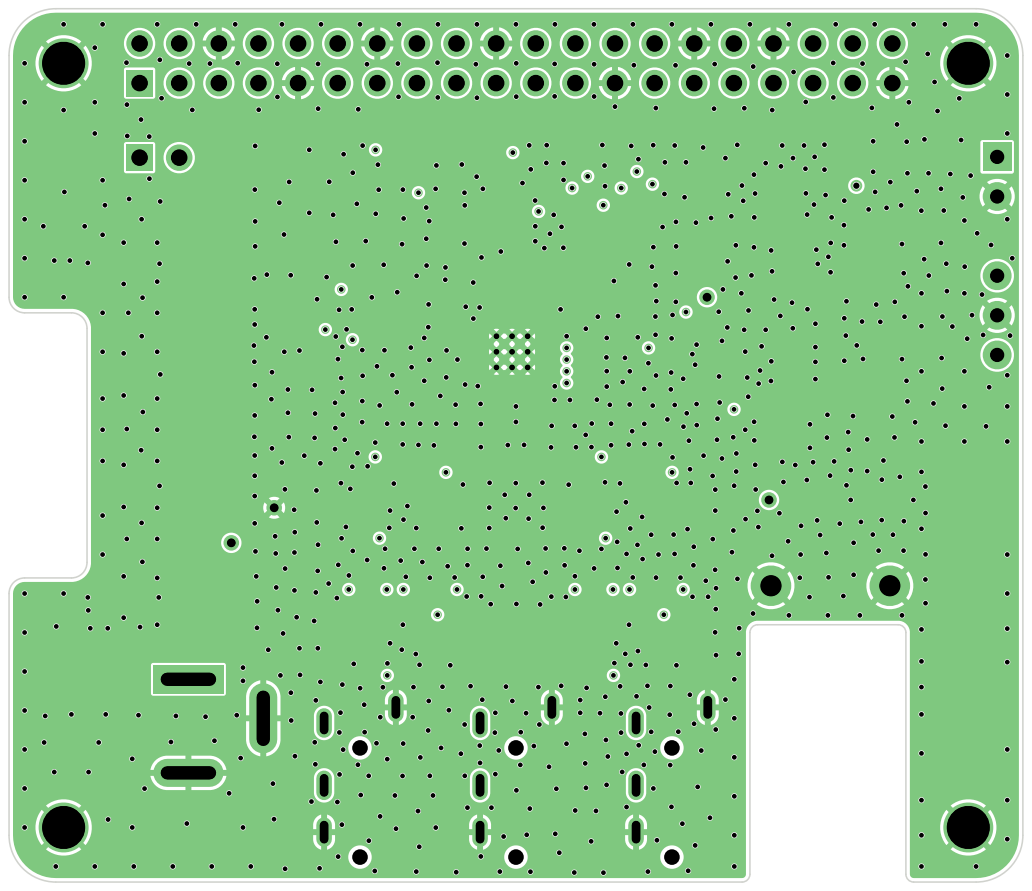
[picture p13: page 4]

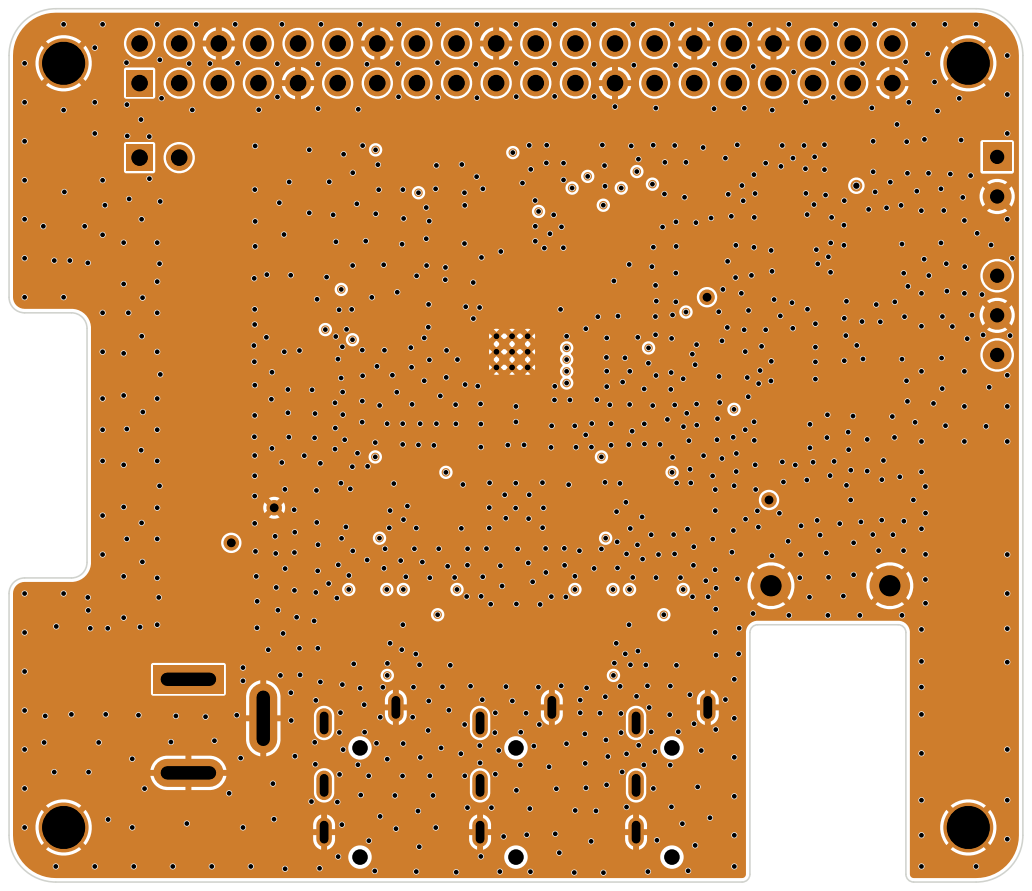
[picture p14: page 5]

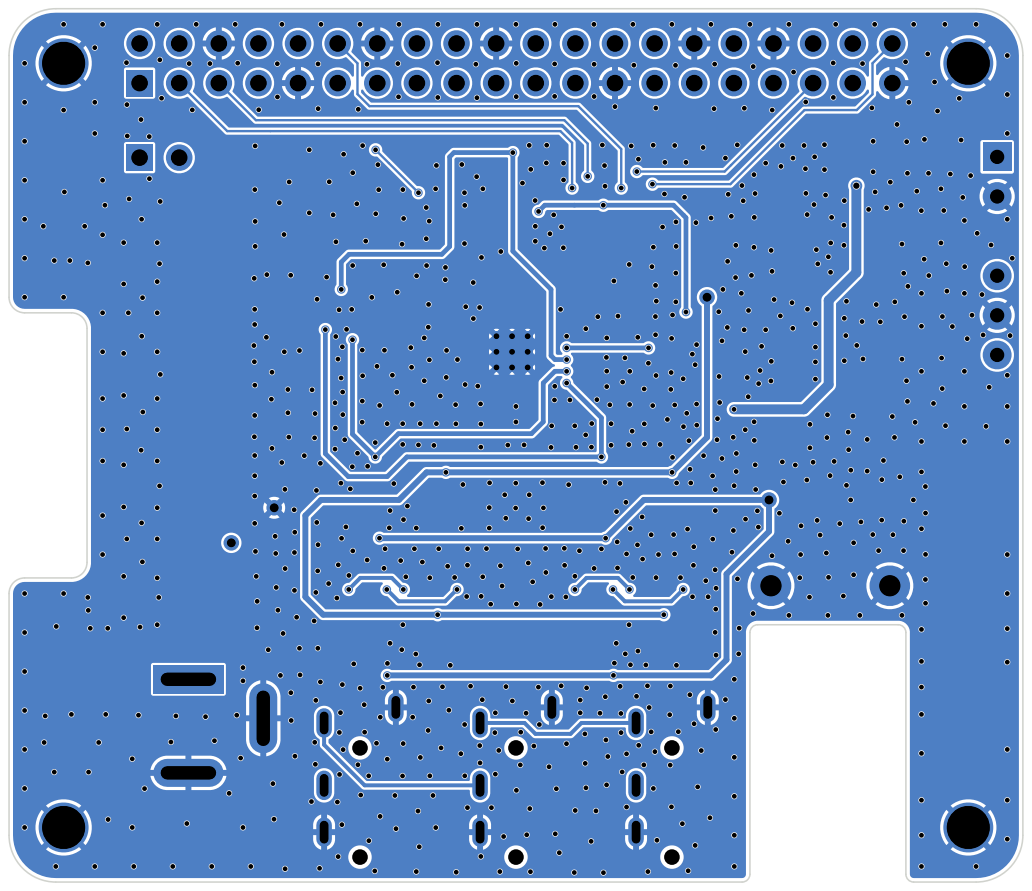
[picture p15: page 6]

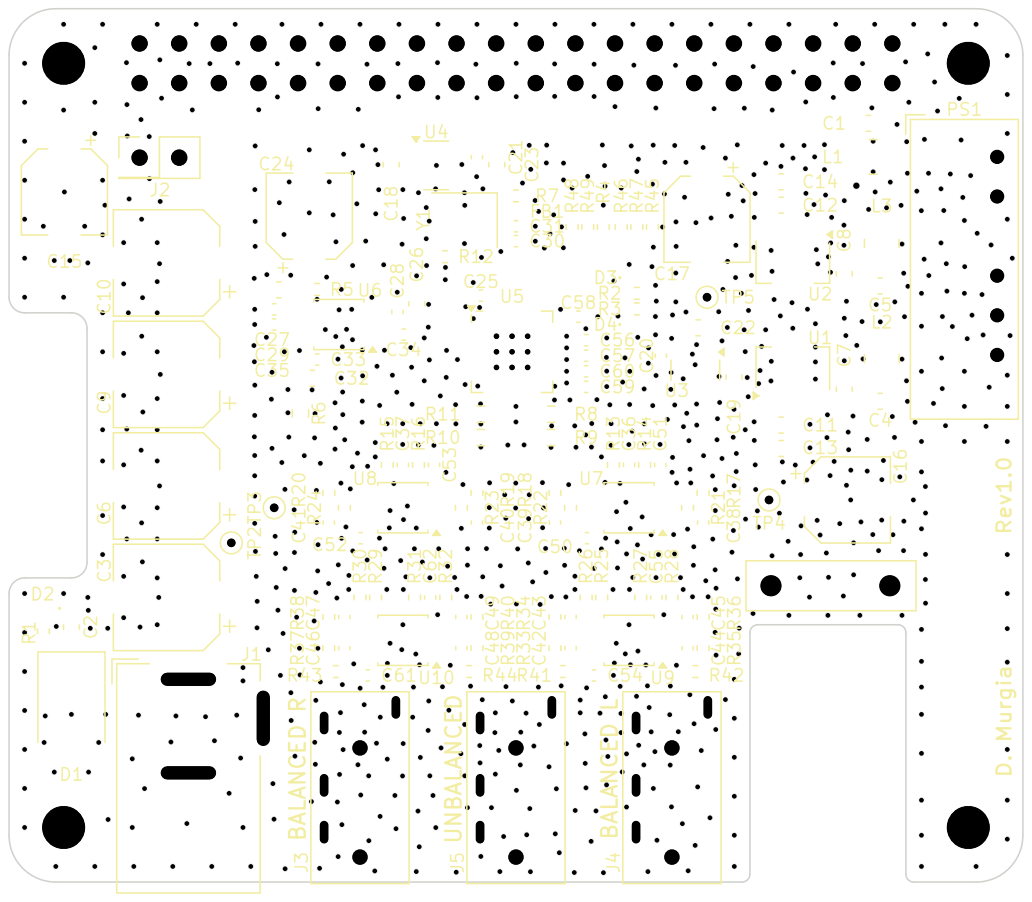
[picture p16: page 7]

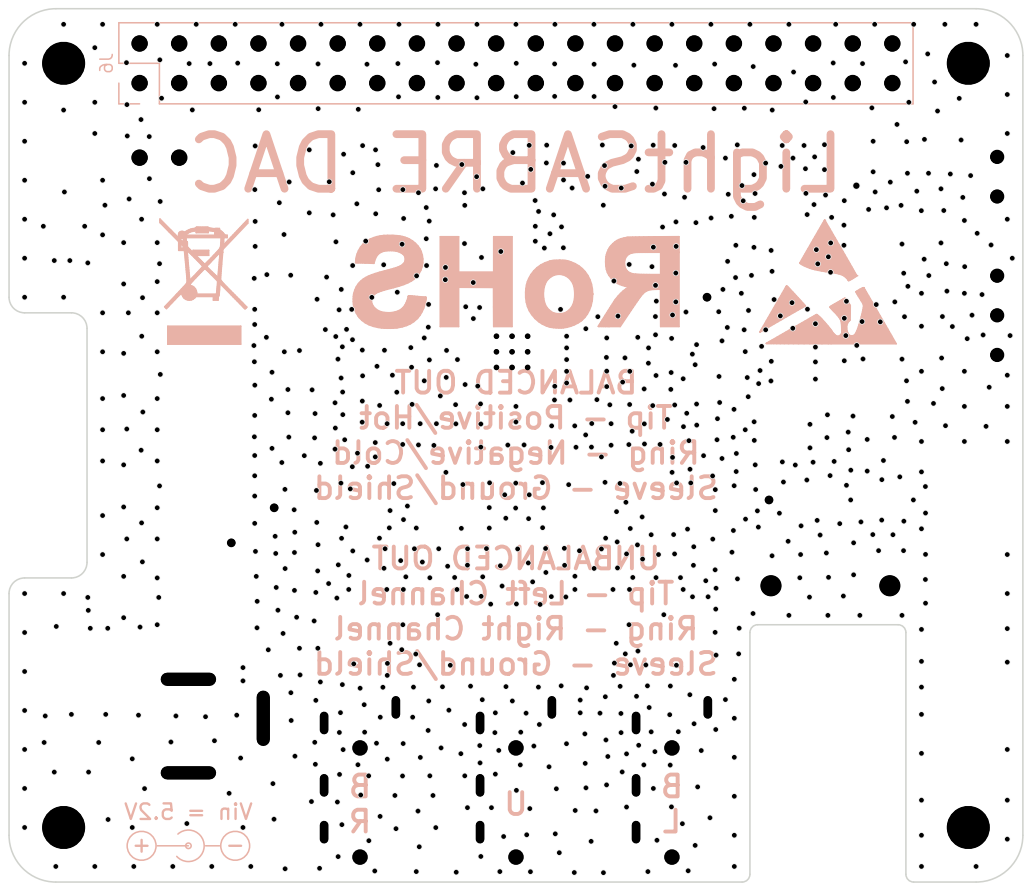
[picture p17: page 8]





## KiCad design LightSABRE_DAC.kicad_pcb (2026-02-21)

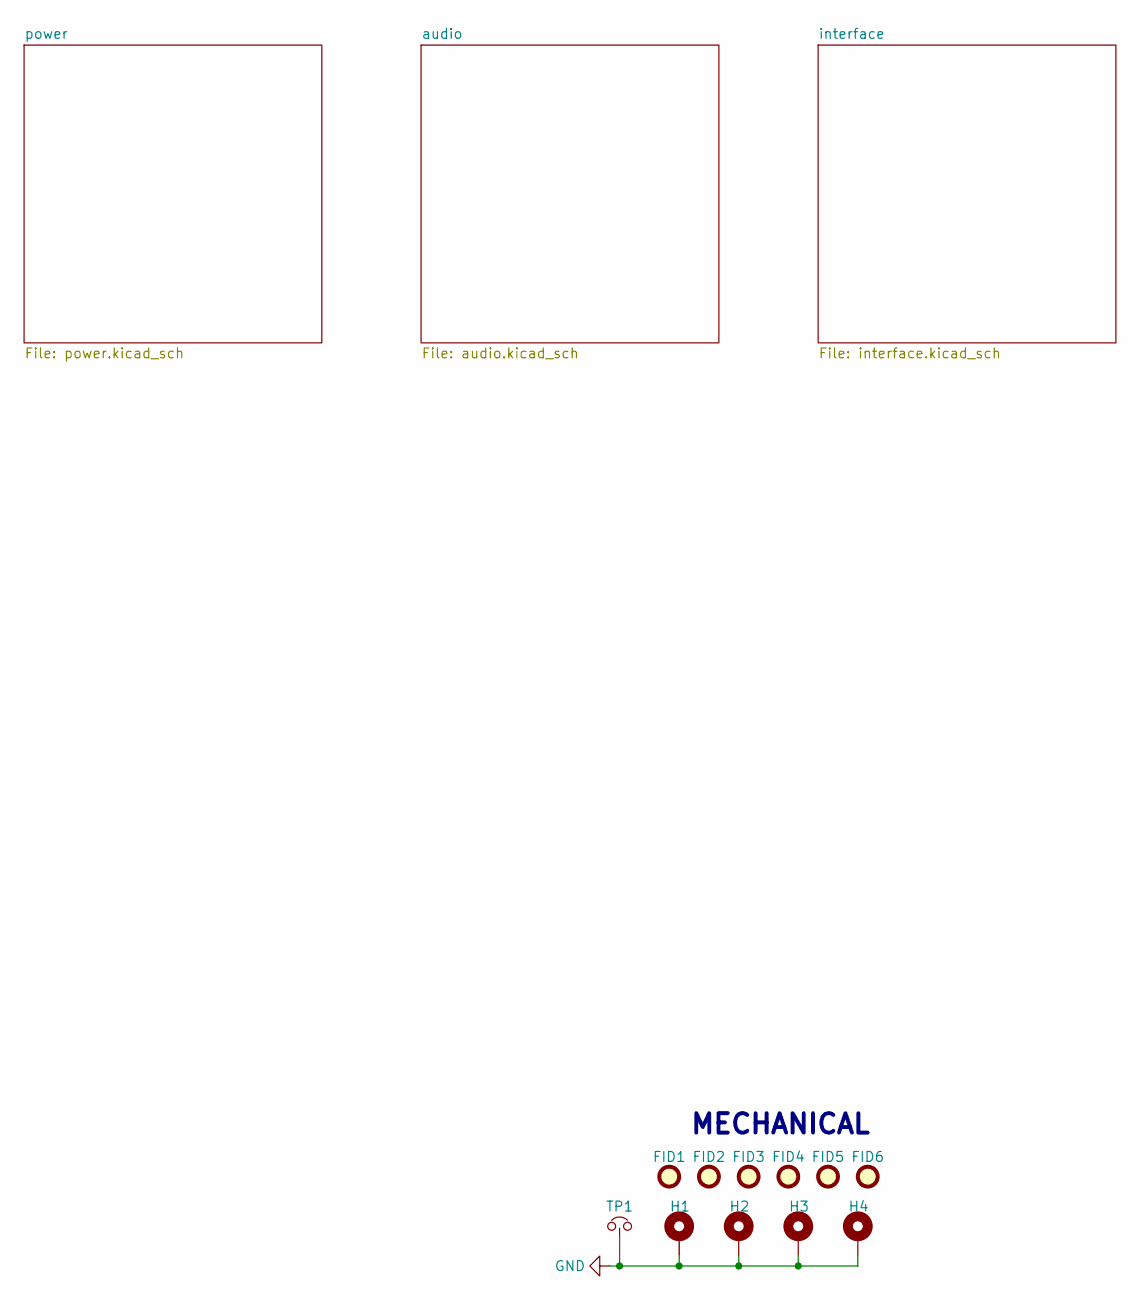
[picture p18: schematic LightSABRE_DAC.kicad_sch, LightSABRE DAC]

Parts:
FID1, FID2, FID3, FID4, FID5, FID6: FID_001; Fiducial_0.5mm_Mask1mm; MPN N.M.; LCSC N.M.
H1, H2, H3, H4: MOUNTING-HOLE-M2.5-SMALL; MOUNTING-HOLE-M2.5-ROUND-2.7MM-3.2MM; MPN N.M.; LCSC N.M.
TP1: GND-TP; TestPoint_Bridge_Pitch7.62mm_Drill1.3mm; MPN N.M.; LCSC N.M.

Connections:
GND: H1.1, H2.1, H3.1, H4.1, TP1.1; also elsewhere on the board

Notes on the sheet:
MECHANICAL

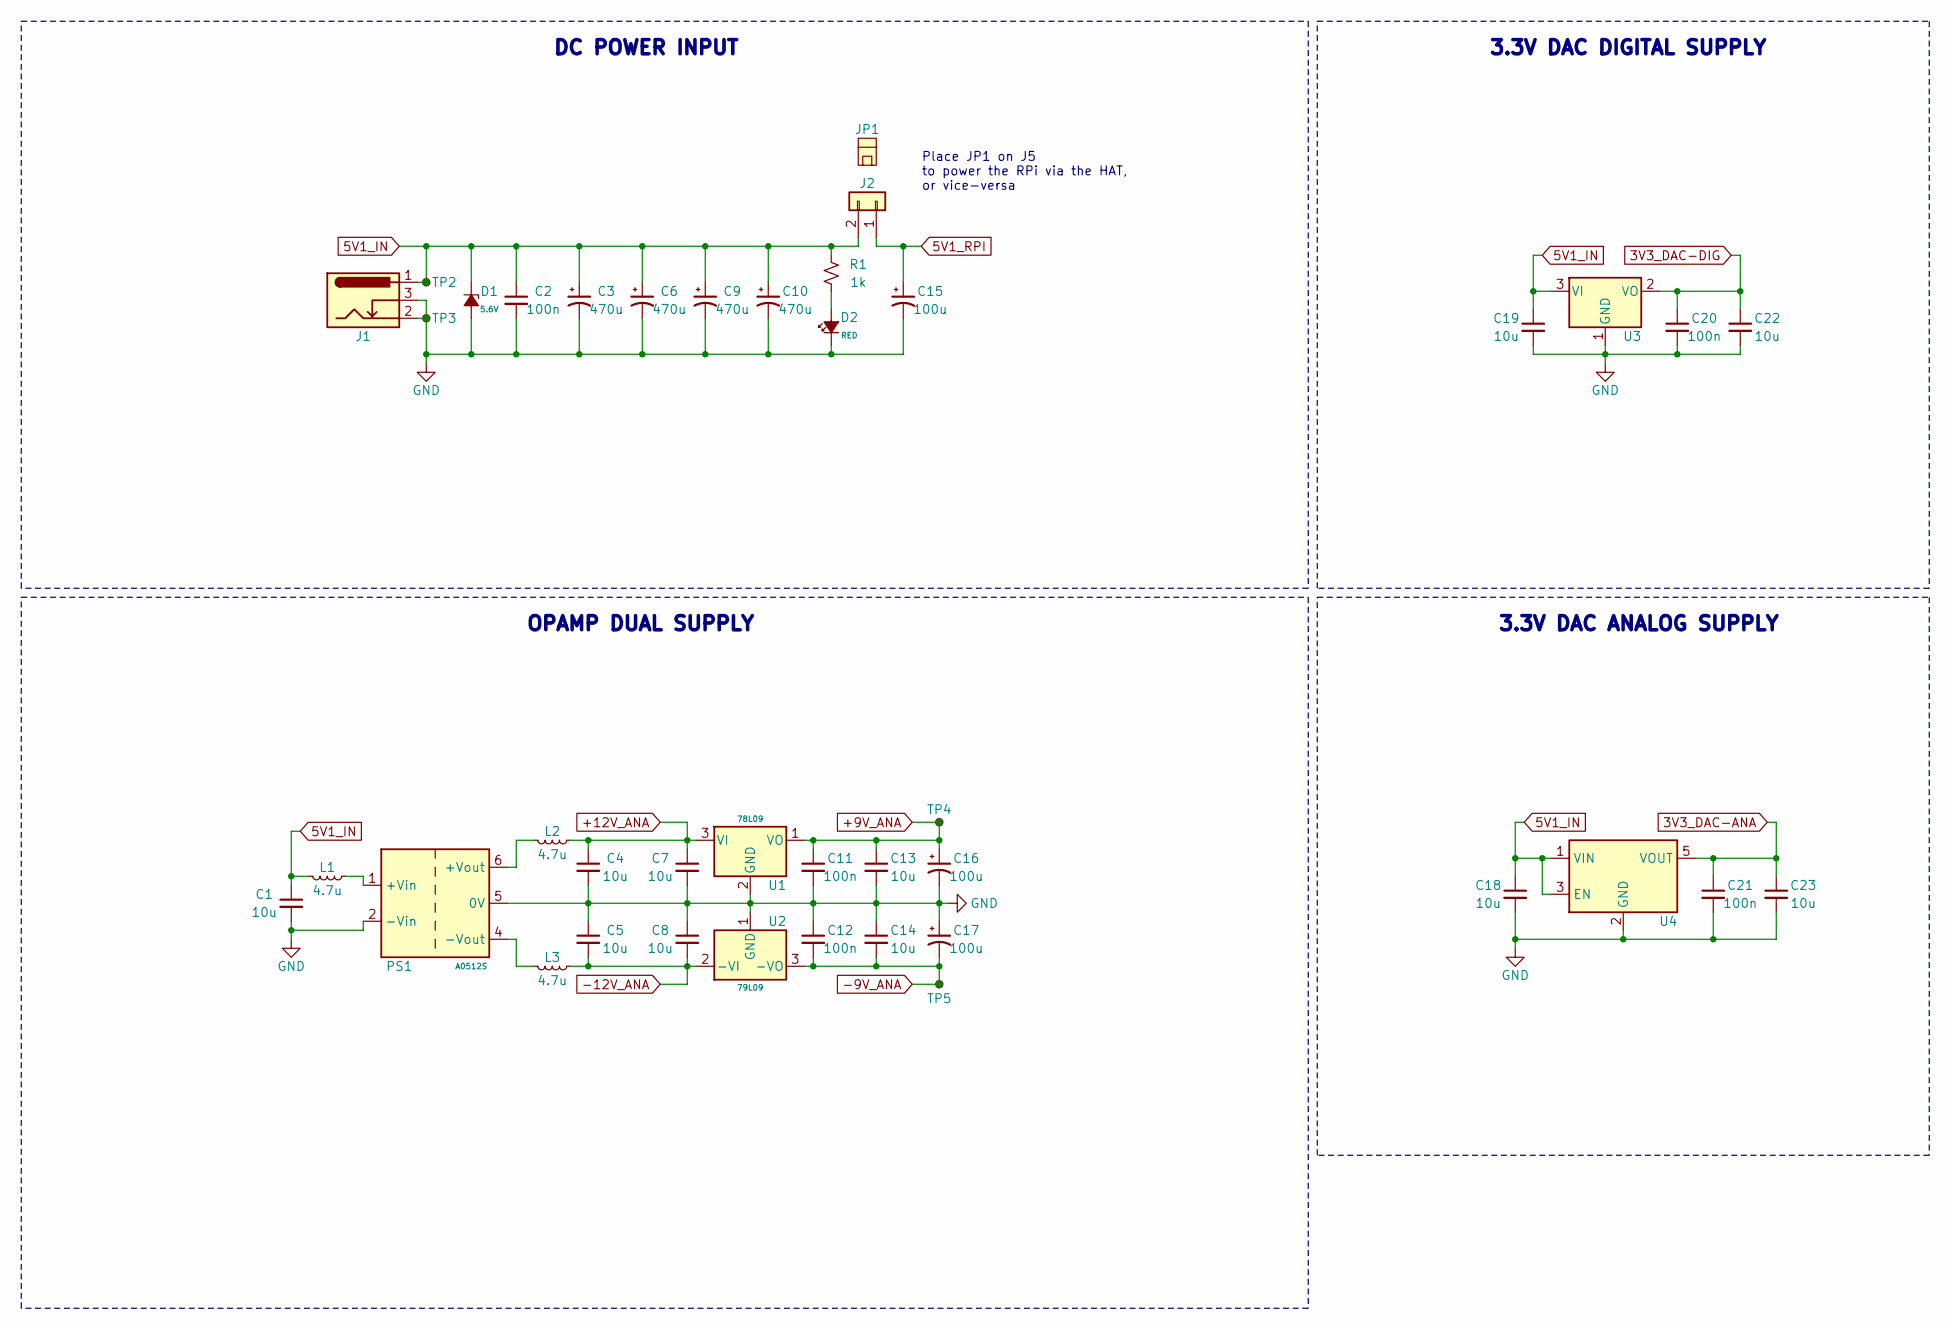
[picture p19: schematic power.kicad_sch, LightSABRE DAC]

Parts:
C1, C4, C5, C7, C8, C13, C14, C18, C19, C22, C23: CAP-10U-20%-16V-X5R-0603_004; C_0603_1608Metric; MPN HGC0603R5106M160NTHJ; LCSC C7472959
C2, C11, C12: CAP-100N-10%-50V-X7R-0603_002; C_0603_1608Metric; MPN CGA0603X7R104K500JT; LCSC C6119867
C3, C6, C9, C10: CAP-EL-470U-20%-10V-ALUM-6.3MM-7.7MM_002; CP_Elec_6.3x7.7; MPN RVT1A471M0607; LCSC C335982
C15, C16, C17: CAP-EL-100U-20%-16V-ALUM-5.0MM-5.4MM_002; CP_Elec_5x5.4; MPN RVT1C101M0505; LCSC C2977550
C20, C21: CAP-100N-10%-16V-X7R-0402_002; C_0402_1005Metric; MPN FCC0402B104K160AT; LCSC C5137468
D1: ZENER-5.6V-5W-SMB_003; D_SMB; Voltage 5.6V; MPN SMBJ5339B; LCSC C5122124
D2: LED-RED-0402_002; LED_0402_1005Metric; MPN XL-1005SURC; LCSC C25503345
J1: BARREL-JACK-SW_002; BarrelJack; MPN DC-005 5.5-2.0MM; LCSC C16214
J2: CONN-HDR-01X02-2.54-TH_002; PinHeader_2x01_P2.54mm_Vertical; MPN C124375; LCSC C124375
JP1: CONN-SHUNT-2P-2.54MM-BLACK-CAPPED_002; MPN HY-2540-B1NIB; LCSC C18185738
L1, L2, L3: IND-4.7U-20%-1.55A-0.196OHM-1008_002; L_1008_2520Metric; MPN WIP252012P-4R7ML; LCSC C964123
PS1: A0512S-2W-1.5KV-SIP_002; Converter_DCDC_XP_POWER-IHxxxxS_THT; MPN A0512S-2WR2; LCSC C5369424
R1: RES-1K-5%-0.063W-0402_002; R_0402_1005Metric; MPN 0402WGJ0102TCE; LCSC C25543
TP2, TP3, TP4, TP5: TP-TH-ROUND-1MM-0.5MM; TestPoint_THTPad_D1.0mm_Drill0.5mm; MPN N.M.; LCSC N.M.
U1: 78L09-SOT89_002; SOT-89-3; MPN 78L09; LCSC C22458782
U2: 79L09-SOT89_002; SOT-89-3; MPN PJ79L09SQ; LCSC C41784049
U3: LR6206B-U33; SOT-23; MPN LR6206B-U33; LCSC C5336486
U4: TPS7A2033-SOT23; SOT-23-5; MPN TPS7A2033PDBVR; LCSC C2862740

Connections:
3V3_DAC-ANA: C21.1, C23.1, U4.5 (VOUT); also elsewhere on the board
3V3_DAC-DIG: C20.1, C22.1, U3.2 (VO); also elsewhere on the board
5V1_IN: C1.1, C2.1, C3.1, C6.1, C9.1, C10.1, C18.1, C19.1, D1.1 (K), J1.1, J2.2, L1.2, R1.1, TP2.1, U3.3 (VI), U4.1 (VIN), U4.3 (EN); also elsewhere on the board
5V1_RPI: C15.1, J2.1; also elsewhere on the board
+9V_ANA: C11.1, C13.1, C16.1, TP4.1, U1.1 (VO); also elsewhere on the board
+12V_ANA: C4.1, C7.1, L2.1, U1.3 (VI)
-9V_ANA: C12.2, C14.2, C17.2, TP5.1, U2.3 (-VO); also elsewhere on the board
-12V_ANA: C5.2, C8.2, L3.1, U2.2 (-VI)
GND: C1.2, C2.2, C3.2, C4.2, C5.1, C6.2, C7.2, C8.1, C9.2, C10.2, C11.2, C12.1, C13.2, C14.1, C15.2, C16.2, C17.1, C18.2, C19.2, C20.2, C21.2, C22.2, C23.2, D1.2 (A), D2.1 (K), J1.2, J1.3, PS1.2 (-Vin), PS1.5 (0V), TP3.1, U1.2 (GND), U2.1 (GND), U3.1 (GND), U4.2 (GND); also elsewhere on the board
unnamed: D2.2 (A), R1.2
unnamed: L1.1, PS1.1 (+Vin)
unnamed: L2.2, PS1.6 (+Vout)
unnamed: L3.2, PS1.4 (-Vout)

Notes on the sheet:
DC POWER INPUT
3.3V DAC DIGITAL SUPPLY
OPAMP DUAL SUPPLY
3.3V DAC ANALOG SUPPLY
Place JP1 on J5 to power the RPi via the HAT, or vice-versa

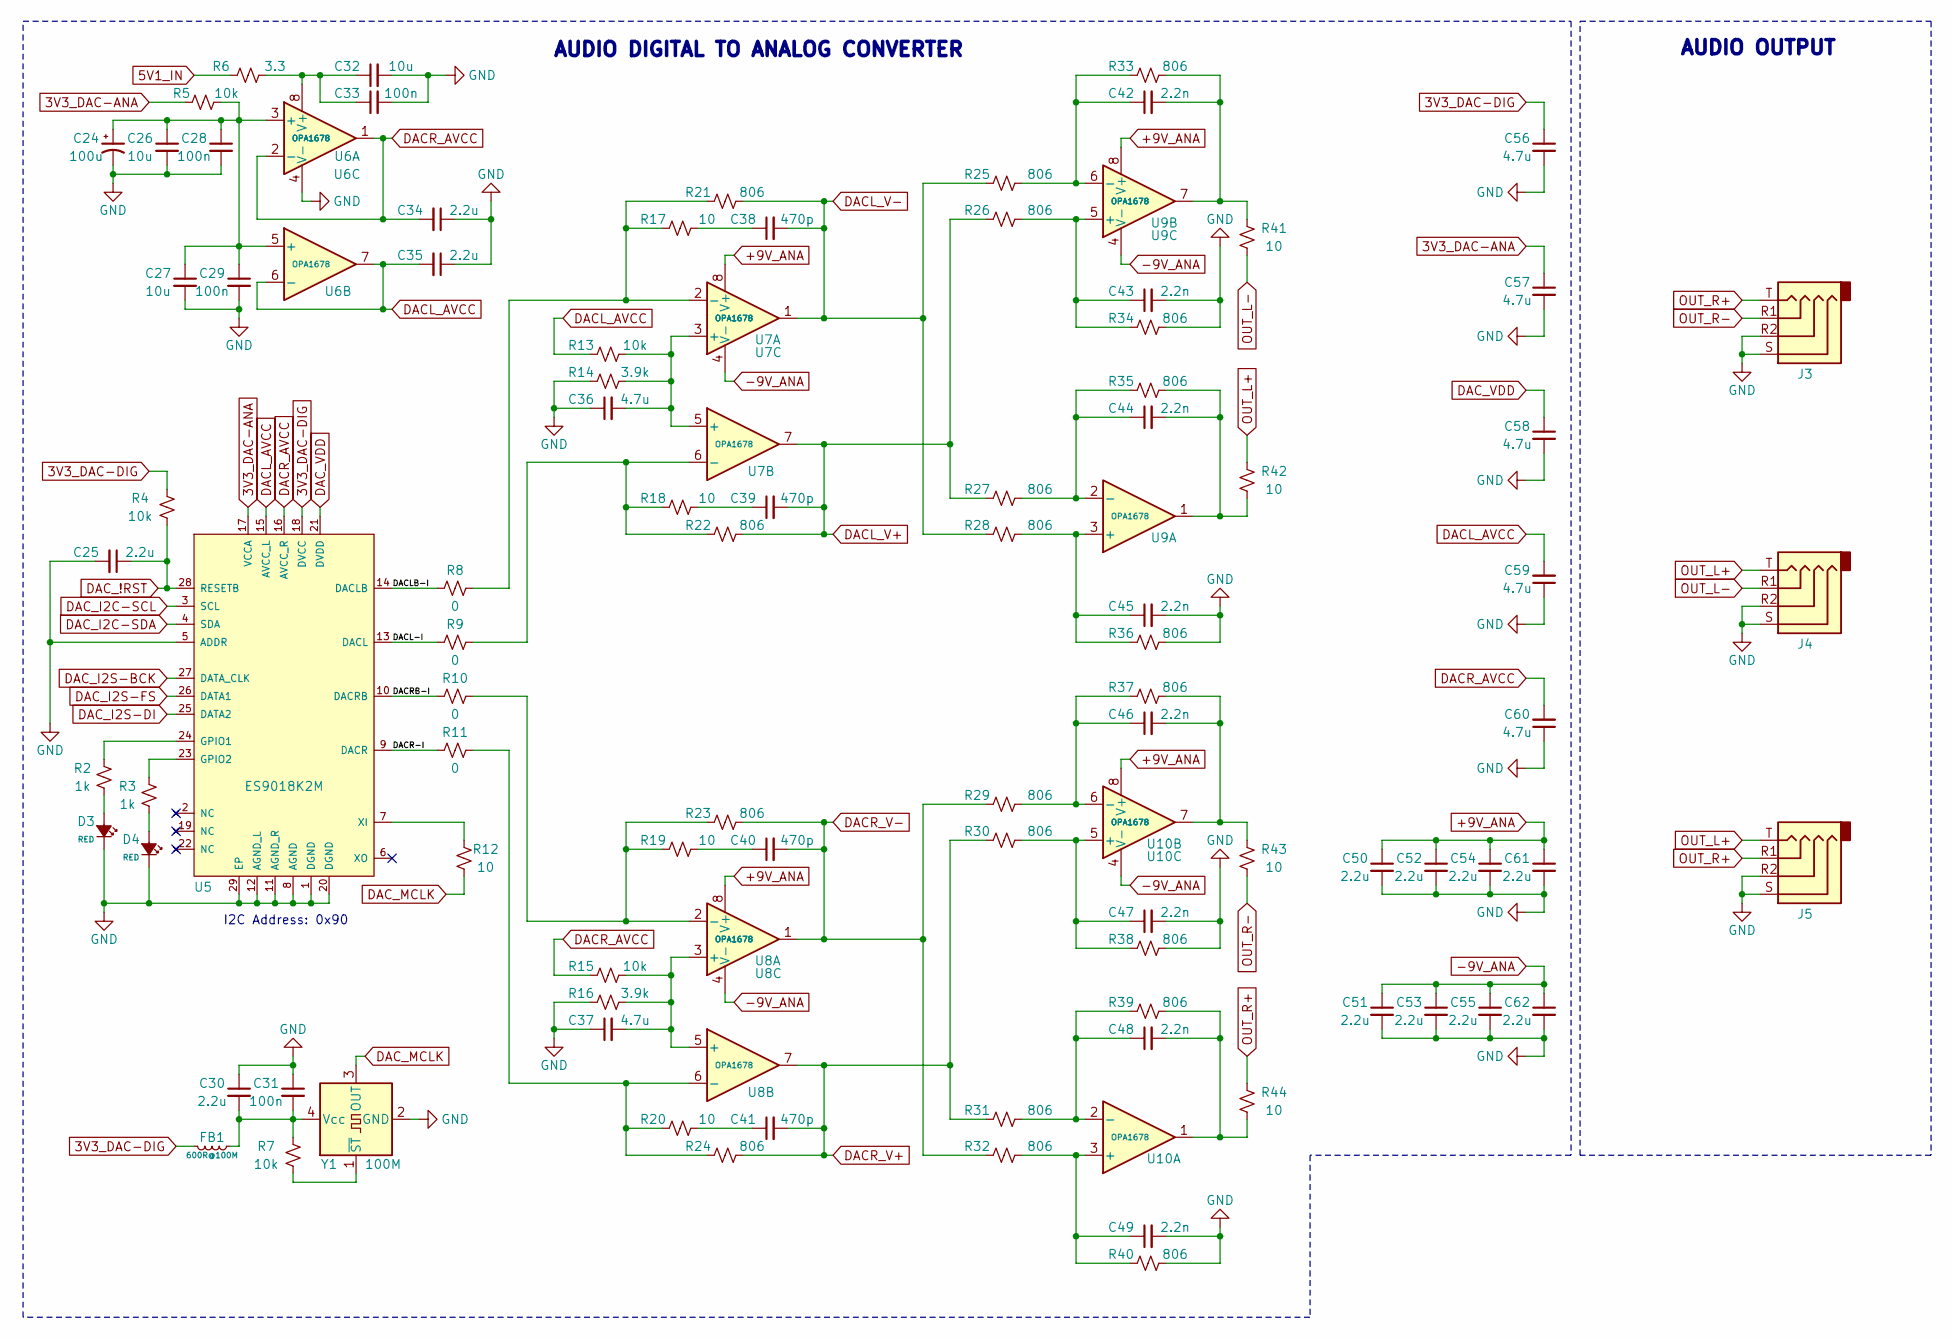
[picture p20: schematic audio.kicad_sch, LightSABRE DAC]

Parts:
C24: CAP-EL-100U-20%-16V-ALUM-5.0MM-5.4MM_002; CP_Elec_5x5.4; MPN RVT1C101M0505; LCSC C2977550
C25, C30, C34, C35, C50, C51, C52, C53, C54, C55, C61, C62: CAP-2.2U-20%-16V-X5R-0402_002; C_0402_1005Metric; MPN CGA0402X5R225M160GT; LCSC C6119773
C26, C27, C32: CAP-10U-20%-16V-X5R-0603_004; C_0603_1608Metric; MPN HGC0603R5106M160NTHJ; LCSC C7472959
C28, C29, C31, C33: CAP-100N-10%-16V-X7R-0402_002; C_0402_1005Metric; MPN FCC0402B104K160AT; LCSC C5137468
C36, C37, C56, C57, C58, C59, C60: CAP-4.7U-20%-10V-X5R-0402_002; C_0402_1005Metric; MPN HGC0402R5475M100NTEJ; LCSC C7472957
C38, C39, C40, C41: CAP-470P-5%-50V-C0G-0402_002; C_0402_1005Metric; MPN CGA0402C0G471J500GT; LCSC C20069335
C42, C43, C44, C45, C46, C47, C48, C49: CAP-2.2N-2%-50V-C0G-0402_001; C_0402_1005Metric; MPN GRM1555C1H222GA01D; LCSC C2987940
D3, D4: LED-RED-0402_002; LED_0402_1005Metric; MPN XL-1005SURC; LCSC C25503345
FB1: FERR-BEAD-600OHM@100MHZ-0.7A-0.34OHM-0402; L_0402_1005Metric; MPN PBY100505T-601Y-N; LCSC C142082
J3, J4, J5: PJ-320A; TRRS-PJ-320A; MPN PJ-320A; LCSC C2884926
R2, R3: RES-1K-5%-0.063W-0402_002; R_0402_1005Metric; MPN 0402WGJ0102TCE; LCSC C25543
R4, R5, R7, R13, R15: RES-10K-1%-0.063W-0402_002; R_0402_1005Metric; MPN RTT021002FTH; LCSC C102749
R6: RES-3.3-1%-0.1W-0603_002; R_0603_1608Metric; MPN FRC0603F3R30TS; LCSC C2930016
R8, R9, R10, R11: RES-0-1%-0.1W-0603_002; R_0603_1608Metric; MPN FRC0603F0000TS; LCSC C2906974
R12, R17, R18, R19, R20, R41, R42, R43, R44: RES-10-1%-0.063W-0402_002; R_0402_1005Metric; MPN FRC0402F10R0TS; LCSC C2906862
R14, R16: RES-3.9K-1%-0.063W-0402_002; R_0402_1005Metric; MPN FRC0402F3901TS; LCSC C2909346
R21, R22, R23, R24, R25, R26, R27, R28, R29, R30, R31, R32, R33, R34, R35, R36, R37, R38, R39, R40: RES-806-0.1%-0.063W-THIN-0402_001; R_0402_1005Metric; MPN RT0402BRD07806RL; LCSC C852922
U5: ES9018K2M; QFN-28-1EP_5x5mm_P0.5mm_EP3.25x3.25mm_ThermalVias_0.3mm; MPN ES9018K2M; LCSC C2688377
U6, U7, U8, U9, U10: OPA1678-VSSOP; MSOP-8_3x3mm_P0.65mm; MPN OPA1678IDGKR; LCSC C2863133
Y1: OSC-XO-100M-3225_002; Oscillator_SMD_4Pin_3.2x2.5mm; MPN O93225100MEDA4SI-13; LCSC C496694

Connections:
3V3_DAC-ANA: C57.1, R5.1, U5.17 (VCCA); also elsewhere on the board
3V3_DAC-DIG: C56.1, FB1.2, R4.1, U5.18 (DVCC); also elsewhere on the board
5V1_IN: R6.1; also elsewhere on the board
+9V_ANA: C50.1, C52.1, C54.1, C61.1, U7.8 (V+), U8.8 (V+), U9.8 (V+), U10.8 (V+); also elsewhere on the board
-9V_ANA: C51.1, C53.1, C55.1, C62.1, U7.4 (V-), U8.4 (V-), U9.4 (V-), U10.4 (V-); also elsewhere on the board
/audio/DACL-I: R9.2, U5.13 (DACL)
/audio/DACLB-I: R8.2, U5.14 (DACLB)
/audio/DACR-I: R11.2, U5.9 (DACR)
/audio/DACRB-I: R10.2, U5.10 (DACRB)
DACL_AVCC: C35.2, C59.2, R13.1, U5.15 (AVCC_L), U6.6 (-), U6.7
DACL_V+: C39.2, R22.2, R26.1, R27.1, U7.7
DACL_V-: C38.2, R21.2, R25.1, R28.1, U7.1
DACR_AVCC: C34.2, C60.2, R15.1, U5.16 (AVCC_R), U6.1, U6.2 (-)
DACR_V+: C41.2, R24.2, R30.1, R31.1, U8.7
DACR_V-: C40.2, R23.2, R29.1, R32.1, U8.1
DAC_!RST: C25.1, R4.2, U5.28 (RESETB)
DAC_I2C-SCL: U5.3 (SCL); also elsewhere on the board
DAC_I2C-SDA: U5.4 (SDA); also elsewhere on the board
DAC_I2S-BCK: U5.27 (DATA_CLK); also elsewhere on the board
DAC_I2S-DI: U5.25 (DATA2); also elsewhere on the board
DAC_I2S-FS: U5.26 (DATA1); also elsewhere on the board
DAC_MCLK: R12.2, Y1.3 (OUT)
DAC_VDD: C58.1, U5.21 (DVDD)
GND: C24.2, C25.2, C26.2, C27.2, C28.2, C29.2, C30.1, C31.1, C32.2, C33.2, C34.1, C35.1, C36.1, C37.1, C43.2, C45.2, C47.2, C49.2, C50.2, C51.2, C52.2, C53.2, C54.2, C55.2, C56.2, C57.2, C58.2, C59.1, C60.1, C61.2, C62.2, D3.1 (K), D4.1 (K), J3.R2, J3.S, J4.R2, J4.S, J5.R2, J5.S, R14.1, R16.1, R34.2, R36.2, R38.2, R40.2, U5.1 (DGND), U5.5 (ADDR), U5.8 (AGND), U5.11 (AGND_R), U5.12 (AGND_L), U5.20 (DGND), U5.29 (EP), U6.4 (V-), Y1.2 (GND); also elsewhere on the board
unnamed: C38.1, R17.2
unnamed: C39.1, R18.2
unnamed: C40.1, R19.2
unnamed: C41.1, R20.2
unnamed: C42.2, R33.2, R41.2, U9.7
unnamed: C44.2, R35.2, R42.1, U9.1
unnamed: C46.2, R37.2, R43.2, U10.7
unnamed: C48.2, R39.2, R44.1, U10.1
unnamed: D3.2 (A), R2.2
unnamed: D4.2 (A), R3.2
unnamed: R2.1, U5.24 (GPIO1)
unnamed: R3.1, U5.23 (GPIO2)
unnamed: R12.1, U5.7 (XI)
unnamed: C24.1, C26.1, C27.1, C28.1, C29.1, R5.2, U6.3 (+), U6.5 (+)
unnamed: C32.1, C33.1, R6.2, U6.8 (V+)
unnamed: C36.2, R13.2, R14.2, U7.3 (+), U7.5 (+)
unnamed: R8.1, R17.1, R21.1, U7.2 (-)
unnamed: R9.1, R18.1, R22.1, U7.6 (-)
unnamed: C37.2, R15.2, R16.2, U8.3 (+), U8.5 (+)
unnamed: R10.1, R19.1, R23.1, U8.2 (-)
unnamed: R11.1, R20.1, R24.1, U8.6 (-)
unnamed: C45.1, R28.2, R36.1, U9.3 (+)
unnamed: C44.1, R27.2, R35.1, U9.2 (-)
unnamed: C43.1, R26.2, R34.1, U9.5 (+)
unnamed: C42.1, R25.2, R33.1, U9.6 (-)
unnamed: C49.1, R32.2, R40.1, U10.3 (+)
unnamed: C48.1, R31.2, R39.1, U10.2 (-)
unnamed: C47.1, R30.2, R38.1, U10.5 (+)
unnamed: C46.1, R29.2, R37.1, U10.6 (-)
unnamed: C30.2, C31.2, FB1.1, R7.2, Y1.4 (Vcc)
unnamed: R7.1, Y1.1 (~ST)
OUT_L+: J4.T, J5.T, R42.2
OUT_L-: J4.R1, R41.1
OUT_R+: J3.T, J5.R1, R44.2
OUT_R-: J3.R1, R43.1

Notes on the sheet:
AUDIO OUTPUT
AUDIO DIGITAL TO ANALOG CONVERTER
I2C Address: 0x90

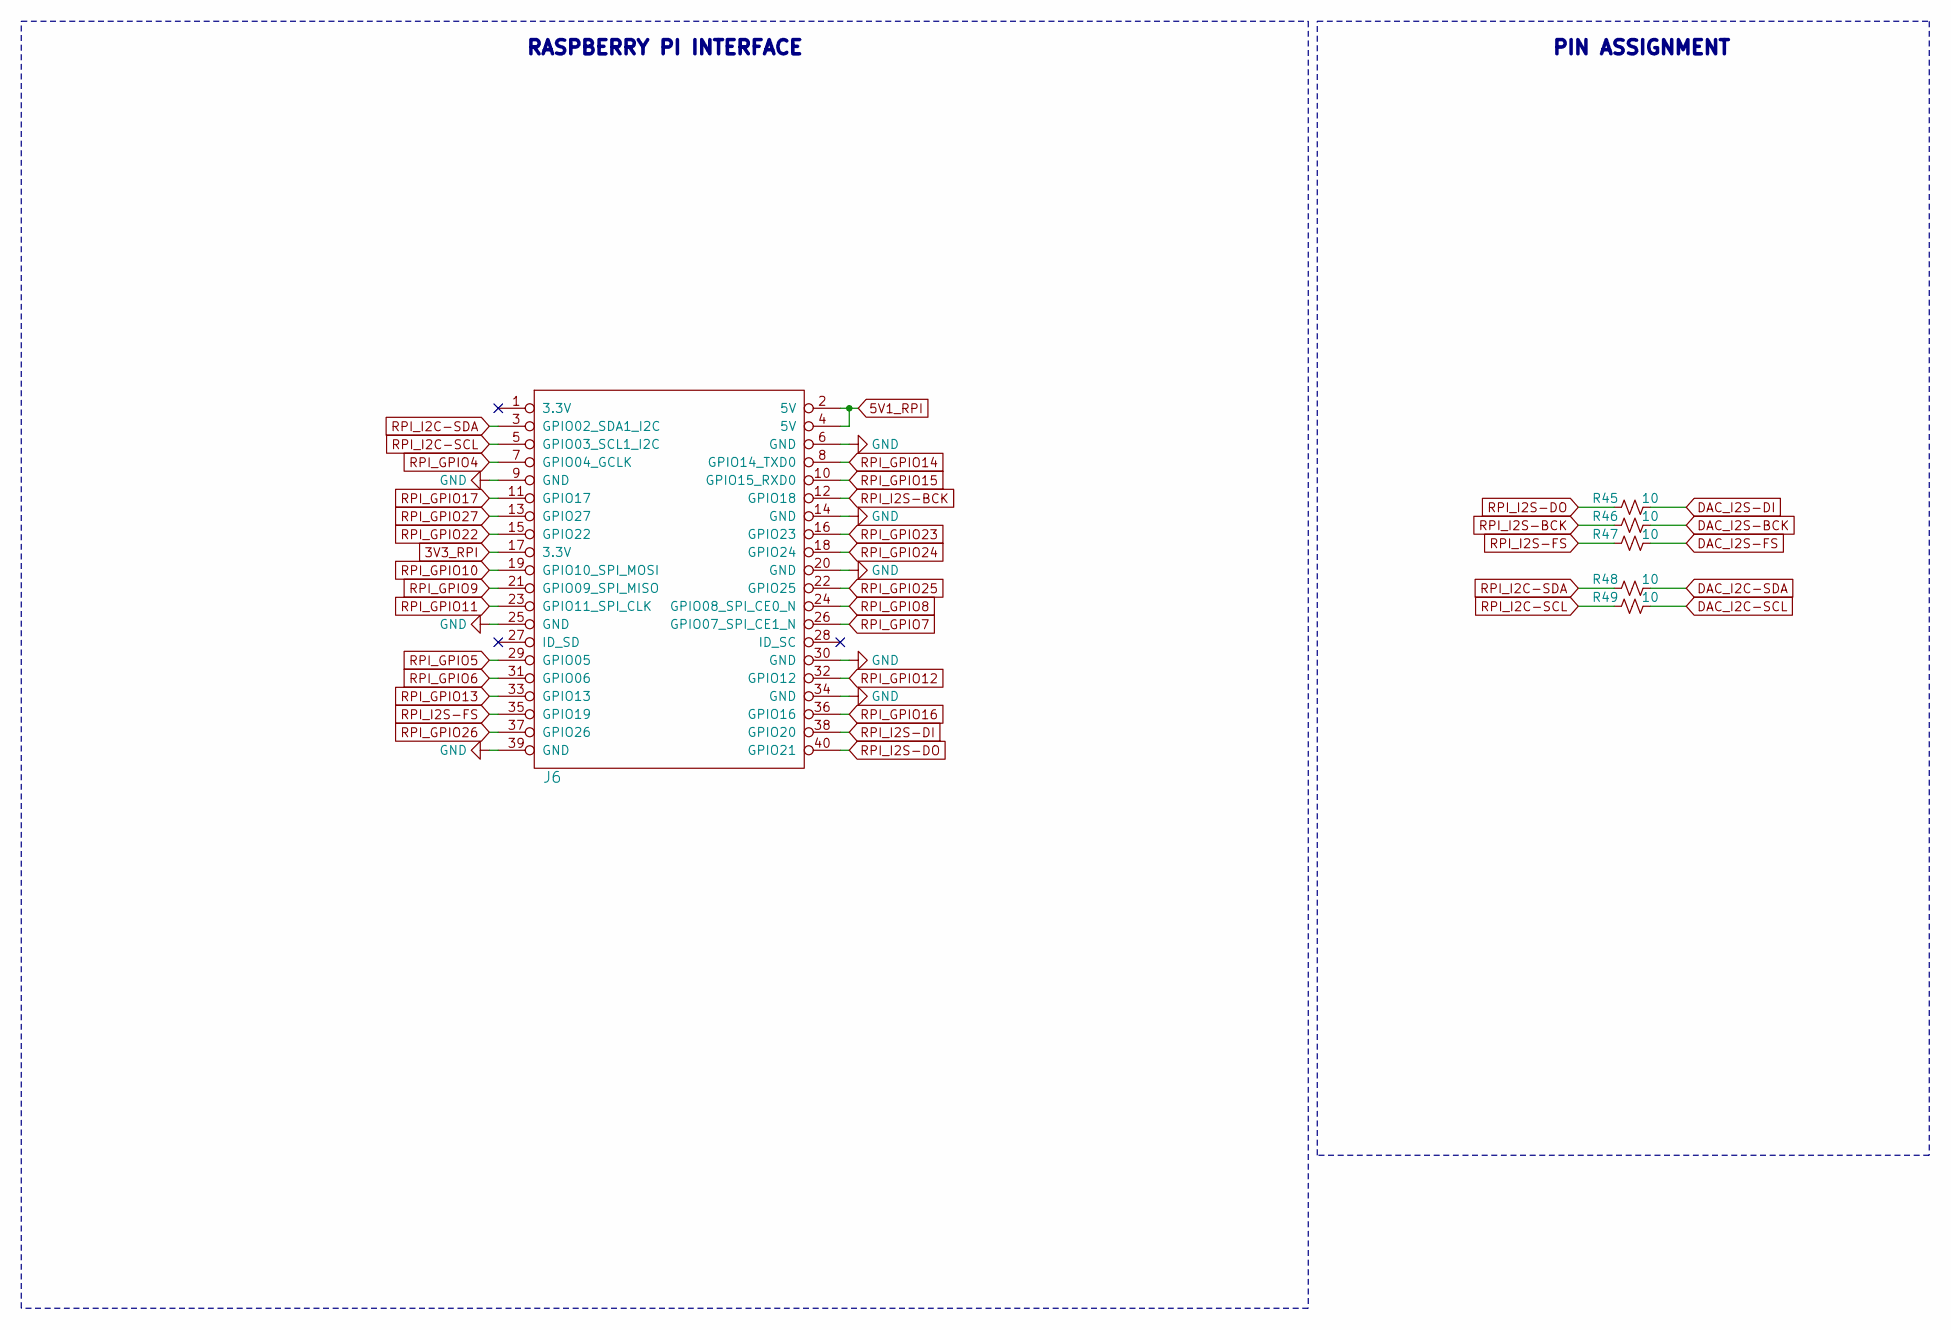
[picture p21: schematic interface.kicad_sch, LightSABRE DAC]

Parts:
J6: RPi-GPIO-SKT-TH-EXT_002; SKT-02x20-TH-EXT; MPN 2.54-2*20PPC104; LCSC C35165
R45, R46, R47, R48, R49: RES-10-1%-0.063W-0402_002; R_0402_1005Metric; MPN FRC0402F10R0TS; LCSC C2906862

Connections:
3V3_RPI: J6.17 (3.3V)
5V1_RPI: J6.2 (5V), J6.4 (5V); also elsewhere on the board
DAC_I2C-SCL: R49.2; also elsewhere on the board
DAC_I2C-SDA: R48.2; also elsewhere on the board
DAC_I2S-BCK: R46.2; also elsewhere on the board
DAC_I2S-DI: R45.2; also elsewhere on the board
DAC_I2S-FS: R47.2; also elsewhere on the board
GND: J6.6 (GND), J6.9 (GND), J6.14 (GND), J6.20 (GND), J6.25 (GND), J6.30 (GND), J6.34 (GND), J6.39 (GND); also elsewhere on the board
RPI_GPIO4: J6.7 (GPIO04_GCLK)
RPI_GPIO5: J6.29 (GPIO05)
RPI_GPIO6: J6.31 (GPIO06)
RPI_GPIO7: J6.26 (GPIO07_SPI_CE1_N)
RPI_GPIO8: J6.24 (GPIO08_SPI_CE0_N)
RPI_GPIO9: J6.21 (GPIO09_SPI_MISO)
RPI_GPIO10: J6.19 (GPIO10_SPI_MOSI)
RPI_GPIO11: J6.23 (GPIO11_SPI_CLK)
RPI_GPIO12: J6.32 (GPIO12)
RPI_GPIO13: J6.33 (GPIO13)
RPI_GPIO14: J6.8 (GPIO14_TXD0)
RPI_GPIO15: J6.10 (GPIO15_RXD0)
RPI_GPIO16: J6.36 (GPIO16)
RPI_GPIO17: J6.11 (GPIO17)
RPI_GPIO22: J6.15 (GPIO22)
RPI_GPIO23: J6.16 (GPIO23)
RPI_GPIO24: J6.18 (GPIO24)
RPI_GPIO25: J6.22 (GPIO25)
RPI_GPIO26: J6.37 (GPIO26)
RPI_GPIO27: J6.13 (GPIO27)
RPI_I2C-SCL: J6.5 (GPIO03_SCL1_I2C), R49.1
RPI_I2C-SDA: J6.3 (GPIO02_SDA1_I2C), R48.1
RPI_I2S-BCK: J6.12 (GPIO18), R46.1
RPI_I2S-DI: J6.38 (GPIO20)
RPI_I2S-DO: J6.40 (GPIO21), R45.1
RPI_I2S-FS: J6.35 (GPIO19), R47.1

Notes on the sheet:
PIN ASSIGNMENT
RASPBERRY PI INTERFACE

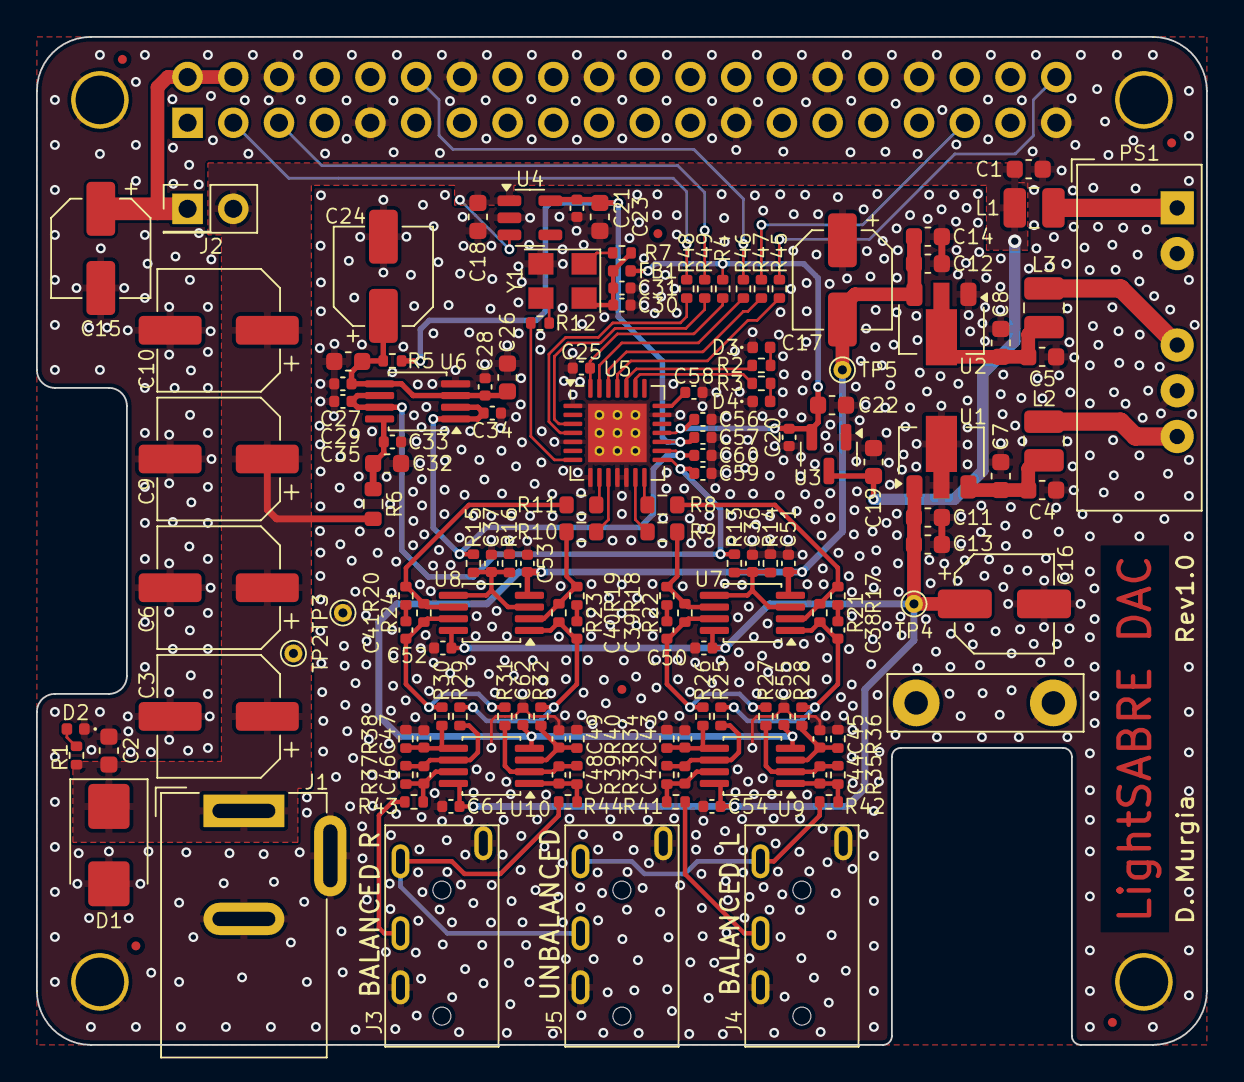
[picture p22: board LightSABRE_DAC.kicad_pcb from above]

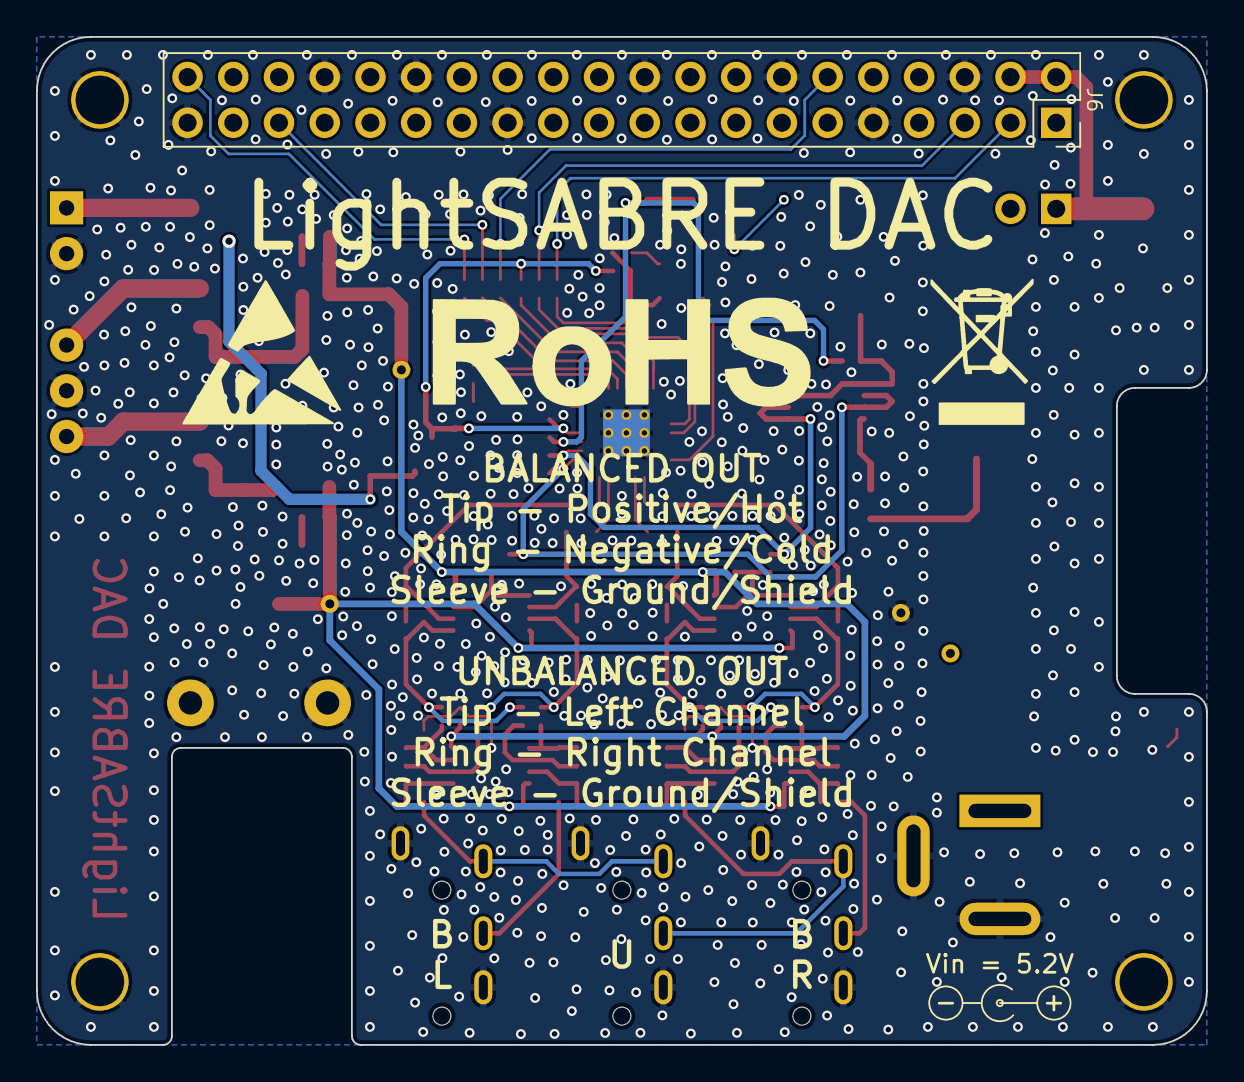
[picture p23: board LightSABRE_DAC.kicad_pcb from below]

Board: 4 copper layers, 65.0 x 56.0 mm, 156 parts (5 on the bottom side), 71 nets.

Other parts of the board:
GFX1: Symbol_Barrel_Polarity
GFX2: WEEE-Logo_5.6x8mm_SilkScreen
GFX3: ESD-Logo_8.9x8mm_SilkScreen
GFX4: RoHS-Logo_6mm_SilkScreen
